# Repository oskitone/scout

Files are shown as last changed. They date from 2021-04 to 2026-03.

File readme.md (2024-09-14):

# Scout

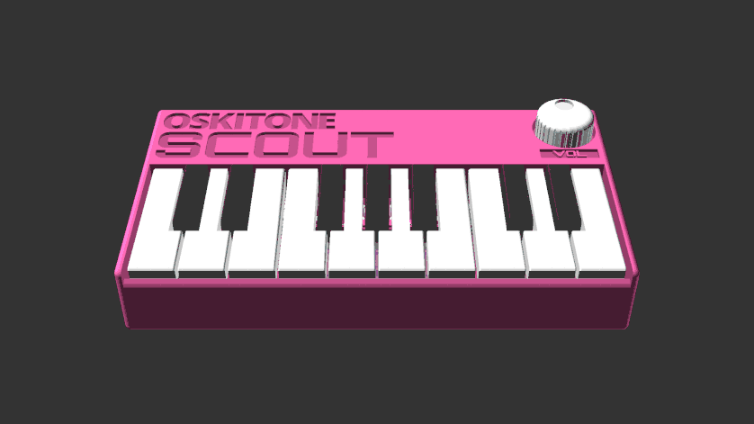
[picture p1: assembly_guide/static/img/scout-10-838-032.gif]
Scout


**scout** (_/skout/_):

1. _One sent to obtain information_
2. _Jean Louise “Scout” Finch, of Atticus Finch_
3. _The first synth from Oskitone to venture into the big ol' world of microcontrollers_

The Scout is:

- **Beginner-friendly:** All components are through-hole (instead of surface mount) for easier soldering, and full assembly takes about 45min. Standalone, battery-powered, doesn't need a computer or external speakers to work. Fun!
- **3D-Printable:** Besides the electronics and nuts and bolts, all parts are 3D-printed. And with a total width of ~160mm (about 6.3"), the Scout can fit on smaller, "Mini" (18x18x18cm) size print beds.
- **Hackable:** Arduino-compatible and fully open source! Hook up an [FTDI Serial TTL-232 cable](https://www.adafruit.com/product/70) (sold separately) to update its code using the Arduino IDE.
- **Minimally featured:** 1.5 octaves of keys, a volume knob, on/off switch, speaker, headphone jack. Monophonic square wave with fixed glide and octave.

In addition to it being the first microcontroller-controlled instrument from Oskitone, the Scout would also make a fine introductory DIY instrument for the budding electronics hobbyist. (Some experience soldering and a general familiarity with how electricity works are recommended though!)

As such, it is intentionally minimal, with the goal of the shortest possible time from starting the kit to making music with it. No MIDI/CV or other IO, as is. If you're looking for a full-featured studio instrument, this ain't it, bub! :)

**Demo:** [https://vimeo.com/587660426](https://vimeo.com/587660426)<br />
**Purchase a kit:** [https://www.oskitone.com/product/scout-synth-diy-electronics-kit](https://www.oskitone.com/product/scout-synth-diy-electronics-kit)<br />
**Assembly guide:** [https://oskitone.github.io/scout/](https://oskitone.github.io/scout/)<br />
**Blog post:** [https://blog.tommy.sh/posts/scout/](https://blog.tommy.sh/posts/scout/)

## 3D Models

The Scout's 3D-printed models are written in OpenSCAD.

### Dependencies

Assumes `poly555` and `apc` repos are in a sibling directory and are _both up to date_ on the `main` branch. Here's how I've got it:

    \ oskitone
        \ apc
        \ poly555
        \ scout

You'll also need to install the [Orbitron](https://fonts.google.com/specimen/Orbitron) font.

### Building

STLs are generated with `make_stls.sh`. Run `./make_stls.sh -h` for full flags list.

### Changelog

- **September 6, 2021:** Loosen knob fit on pot shaft (6cce7a7)
- **August 9, 2021:** Init (9b5ffe5)

## Documentation

To develop, `cd assembly_guide` then `npm run start`.

<!--
FOR TOMMY, to deploy:
GIT_USER=rocktronica USE_SSH=true npm run deploy
-->

## License

Designed by Oskitone. Please support future synth projects by purchasing from [Oskitone](https://www.oskitone.com/).

Creative Commons Attribution/Share-Alike, all text above must be included in any redistribution. See license.txt for additional details.

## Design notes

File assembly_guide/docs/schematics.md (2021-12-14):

---
id: schematics
title: "Schematics"
description: Scout circuit schematics
sidebar_label: Schematics
image: /img/schematics/scout.svg
hide_table_of_contents: true
---

Scout schematic

Scout keyboard_matrix schematic

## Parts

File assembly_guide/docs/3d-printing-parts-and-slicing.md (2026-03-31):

---
id: 3d-printing-parts-and-slicing
title: 3D-Printing Parts and Slicing
description: How to 3D-print your Scout's parts.
sidebar_label: Parts and Slicing
image: /img/scout_3d_printed_parts.png
slug: /3d-printing-parts-and-slicing
---

:::note
If you bought a kit with 3D-printed parts included, you can skip this section, but do [open up the enclosure](opening-the-enclosure.md) and confirm you have all the right pieces ready before continuing.
:::

## Download

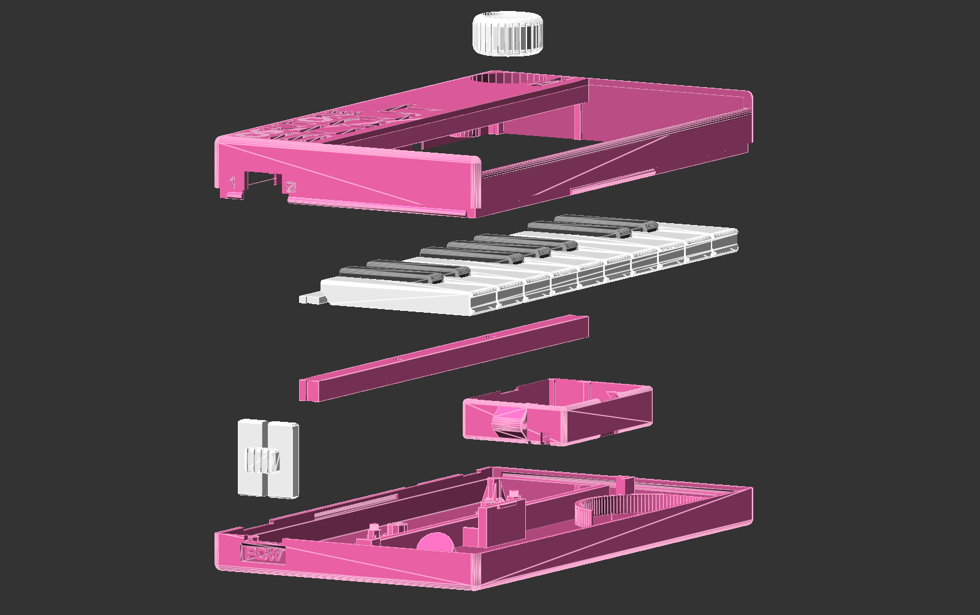
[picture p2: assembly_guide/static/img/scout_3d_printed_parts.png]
Scout 3D-printed parts


Download STLs of the models on [Thingiverse](https://www.thingiverse.com/thing:4933700) or [Printables](https://www.printables.com/model/76472-scout-synth).

## Slicing

There are seven files to print, taking about 11 hours total.

| Part | Layer Height | Supports? | Color change at height | Estimated Time |
| --- | --- | --- | --- | --- |
| battery_holder | .2mm | No | n/a | 40min |
| enclosure_bottom | .2mm | No | n/a | 3hr 10min |
| enclosure_top | .2mm | No | n/a | 3hr |
| keys_mount_rail  | .2mm | No | n/a | 30min |
| keys | .2mm | No | 7.2mm | 3hr |
| knob | .2mm | No | n/a | 20min |
| switch_clutch | .2mm | No | n/a | 20min |

**Notes:**

- Models assume Fused Deposition Modeling with a standard .4mm nozzle. Using a bigger nozzle will likely result in a loss of detail (like missing "VOL" label text on the enclosure_top) and possibly missing internal walls.
- You may find the bottoms of the keys stick together because the plastic has expanded too far into the gap between them. See if your slicer has a setting called something like ["Elephant foot compensation"](https://help.prusa3d.com/en/article/elephant-foot-compensation_114487). Otherwise you'll need to carefully cut off the excess plastic with a utility knife.
- The 3D-printed parts were designed using PLA. Other filament types like ABS are not recommended and will likely have fit or tolerance issues. (If you find that you need to drill or file your prints, that's a good sign there'll be other problems too.)
- 20% infill works well across all models. I wouldn't advise going lower than 15% on the keys.
- Some slicers have trouble with the "color change" GCODE. Try a smaller test print first if you're unfamiliar, and maybe try "pause at layer" instead of "color change".
- Any supports the models need they'll already have, they'll already be rotated to the correct orientation for printing, and they shouldn't need brims. Brims on the keys, in fact, could cause warping on removal. (If you're experimenting with not using FDM, try the `*-no_support` STLs that don't have supports.)
- Watch the first couple layers of the enclosure pieces while printing, especially around the text engravings -- if you see bad adhesion, stop the print to remedy the situation and start again.
- If the prints aren't fitting together well, check to see that the corners aren't bulging. See if your slicer has settings for "coasting" or "linear advance."
- The enclosure_top and switch_clutch both have narrow support walls that will break off when they're done printing.
- If your slicer has it, you can experiment with "variable layer height", but pay attention to the details on the enclosure's text engravings and the aforementioned supports.
- Similarly, you may also like to play around with "ironing" the tops of the keys to make them shiny and flat. _This will significantly increase print time!_

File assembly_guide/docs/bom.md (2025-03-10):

---
id: bom
title: Annotated BOM
description: Bill of Materials, annotated.
sidebar_label: Annotated BOM
image: /img/scout_assembly-16-420-8-128.gif
slug: /bom
hide_table_of_contents: true
---

| Designator | Designation | Quantity | Marking | Usage |
| --- | --- | --- | --- | --- |
| BT1 | 3.6v-4.5v | 1 | n/a | Power; wires to 3\*AAA battery pack |
| C1,C5 | 220uF | 2 | n/a | Big bypass cap, Amp output |
| C3 | 1uF | 1 | n/a | Amp gain |
| C2,C4,C6 | .1uF | 3 | 104 | Bypass caps, RESET pin cap (C4) |
| D1 | LED_CRGB | 1 | n/a | On/off+playing indicators |
| J1 | AudioJack2_SwitchT | 1 | n/a | Line out headphone jack |
| J2 | Conn_01x06_Male | 1 | n/a | Programming header |
| LS1 | Speaker, AZ40R 40mm x 5mm | 1 | n/a | Wires to output speaker |
| R1,R2 | 220 | 2 | Red Red Brown | LED current limiters |
| R3,R5 | 10k | 2 | Brown Black Orange | Brings volume closer to ear-safe level for line out, "pull up" resistor for RESET pin |
| R4 | 1m | 1 | Brown Black Green  | Drops volume even more before amp |
| RV1 | 10k Log, RV09AF-40-20K-A10K | 1 | n/a | Volume control |
| SW1 | SPDT, OS102011MA1QN1 | 1 | n/a | On/off power switch |
| SW2-SW18 | SPST, 6mm tall | 17 | n/a | Key buttons |
| U1 | ATmega328P-PU with bootloader | 1 | n/a | Microcontroller chip |
| U2 | LM386 | 1 | n/a | Amplifier chip |
| Y1 | 16.00MHz | 1 | n/a | Ceramic oscillator for microcontroller |

Also:

- 2 2-wire ribbon cables (or similar small gauge, stranded wire)
  - 1 7" for BT1
  - 1 3" for LS1
- 4 battery terminal contacts for BT1
  - 2 dual spring+button wire contacts (Keystone 181)
  - 1 tabbed spring contact (Keystone 5204)
  - 1 tabbed button contact (Keystone 5226)
- 2 DIP sockets
  - 1 28 pin for U1
  - 1 8 pin for U2
- 4 nuts and bolts
  - 2 4/40 square nuts
  - 2 4/40 3/4" machine screws

Alternate speakers for the AZ40R:

- PSR-40N08A05-JQ
- AS04008MR-21-R
- CMS-4051-058SP

Any circular 8ohm speaker that matches the dimensions will probably work, thought you may find you need a bit of hot glue to hold it in place.

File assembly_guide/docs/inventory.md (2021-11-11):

---
id: inventory
title: Inventory
description: What you'll need to gather before getting started.
sidebar_label: Inventory
image: /img/scout-10-838-032.gif
slug: /inventory
---

#### Required

- The [Oskitone Scout Synth DIY Electronics Kit](http://www.oskitone.com/product/scout-synth-diy-electronics-kit) and its 3D-printed parts
- Soldering iron and solder specifically for electronics
- Wire stripper or cutters
- 3 AAA batteries
- Headphones

#### Recommended

- Multimeter for debugging
- PCB vice or “helping hands” holder
- “Solder sucker” or desoldering braid
- Patience, patience, patience

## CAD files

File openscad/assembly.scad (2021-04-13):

/* TODO: extract into common parts repo */
use <../../poly555/openscad/lib/speaker.scad>;

include <enclosure_bottom.scad>;
include <keyboard_matrix_pcb.scad>;
include <keys.scad>;
include <mounting_rail.scad>;
include <utils.scad>;

peripheral_clearance = 5;

PCB_X = ENCLOSURE_WALL + offset / 2 + key_gutter;
PCB_Y = key_length - PCB_LENGTH + mount_length + ENCLOSURE_WALL + key_gutter;
PCB_Z = ENCLOSURE_FLOOR_CEILING + 2;

BREADBOARD_WIDTH = 35;
BREADBOARD_LENGTH = 50;

ARDUINO_WIDTH = 2.1 * 25.4;
ARDUINO_LENGTH = 2.7 * 25.4;

// https://www.taydaelectronics.com/loud-speaker-8-ohm-3w.html
SPEAKER_DIAMETER = 41.1;
SPEAKER_HEIGHT = 20;
SPEAKER_LENGTH = 71;

peripheral_length = max(BREADBOARD_LENGTH, ARDUINO_LENGTH, SPEAKER_LENGTH);

ENCLOSURE_WIDTH = PCB_X * 2 + PCB_WIDTH;
ENCLOSURE_LENGTH =
    ENCLOSURE_WALL + key_gutter + key_length + mount_length
    + peripheral_length + peripheral_clearance * 2;

DEFAULT_TOLERANCE = .1;

module assembly(
    show_keys = true,
    show_mounting_rail = true,
    show_pcb = true,
    show_peripherals = true,
    show_enclosure_bottom = true,

    tolerance = 0,
    quick_preview = true
) {
    if (show_keys) {
        keys_with_nut_locking_mount(
            tolerance = tolerance,
            quick_preview = quick_preview
        );
    }

    if (show_pcb) {
        e_translate([PCB_X, PCB_Y, PCB_Z]) {
            keyboard_matrix_pcb();
        }
    }

    if (show_enclosure_bottom) {
        enclosure_bottom();
    }

    if (show_mounting_rail) {
        mounting_rail_with_header_cavity();
    }

    if (show_peripherals) {
        y = PCB_Y + PCB_LENGTH - mount_length + mount_length
            + peripheral_clearance;
        z = ENCLOSURE_FLOOR_CEILING;

        height = 20;

        e_translate([peripheral_clearance, y, z]) {
            % cube([ARDUINO_WIDTH, ARDUINO_LENGTH, height]);
        }

        e_translate([peripheral_clearance * 2 + ARDUINO_WIDTH, y, z]) {
            % cube([BREADBOARD_WIDTH, BREADBOARD_LENGTH, height]);
        }

        translate([
            ENCLOSURE_WIDTH - SPEAKER_DIAMETER / 2 - ENCLOSURE_WALL,
            ENCLOSURE_LENGTH - peripheral_length / 2 - peripheral_clearance,
            z
        ]) {
            % speaker(SPEAKER_HEIGHT);
        }
    }
}

SHOW_KEYS = true;
SHOW_MOUNTING_RAIL = true;
SHOW_PCB = true;
SHOW_PERIPHERALS = true;
SHOW_ENCLOSURE_BOTTOM = true;

assembly(
    show_keys = SHOW_KEYS,
    show_mounting_rail = SHOW_MOUNTING_RAIL,
    show_pcb = SHOW_PCB,
    show_peripherals = SHOW_PERIPHERALS,
    show_enclosure_bottom = SHOW_ENCLOSURE_BOTTOM,

    tolerance = DEFAULT_TOLERANCE,
    quick_preview = $preview
);

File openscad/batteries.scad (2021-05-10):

AAA_BATTERY_DIAMETER = 10.5;
AAA_BATTERY_LENGTH = 44.5;

AAA_BATTERY_POSITIVE_CONTACT_MIN_LENGTH = .8;
AAA_BATTERY_POSITIVE_CONTACT_MAX_DIAMETER = 3.8;

AAA_BATTERY_TOTAL_LENGTH = AAA_BATTERY_LENGTH +
    AAA_BATTERY_POSITIVE_CONTACT_MIN_LENGTH;

module battery(
    reverse = false,
    $fn = 24
) {
    module _output() {
        translate([0, AAA_BATTERY_DIAMETER / 2, AAA_BATTERY_DIAMETER / 2]) {
            rotate([0, 90, 0]) {
                cylinder(
                    d = AAA_BATTERY_DIAMETER,
                    h = AAA_BATTERY_LENGTH
                );

                translate([0, 0, AAA_BATTERY_LENGTH]) {
                    cylinder(
                        d = AAA_BATTERY_POSITIVE_CONTACT_MAX_DIAMETER,
                        h = AAA_BATTERY_POSITIVE_CONTACT_MIN_LENGTH
                    );
                }
            }
        }
    }

    if (reverse) {
        translate([AAA_BATTERY_TOTAL_LENGTH, 0, 0]) {
            mirror([1, 0, 0]) {
                _output();
            }
        }
    } else {
        _output();
    }
}

module battery_array(
    count = 3,
    gutter = KEYSTONE_181_GUTTER,

    positive_x = KEYSTONE_181_BUTTON_LENGTH,
    negative_x = KEYSTONE_181_SPRING_COMPRESSED_LENGTH
) {
    plot = AAA_BATTERY_DIAMETER + gutter;

    for (i = [0 : count - 1]) {
        is_odd = i % 2 == 1;

        translate([is_odd ? positive_x : negative_x, i * plot, 0]) {
            battery(reverse = is_odd);
        }
    }
}

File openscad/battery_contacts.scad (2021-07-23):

KEYSTONE_181_HEIGHT = 7;
KEYSTONE_181_CONTACT_X = KEYSTONE_181_HEIGHT / 2;
KEYSTONE_181_CADENCE = 10.5;
KEYSTONE_181_WIDTH = KEYSTONE_181_CADENCE + KEYSTONE_181_CONTACT_X * 2;
KEYSTONE_181_DIAMETER = .5;

KEYSTONE_181_SPRING_LENGTH = 7.2;
KEYSTONE_181_SPRING_COMPRESSED_LENGTH = KEYSTONE_181_SPRING_LENGTH * .25;

KEYSTONE_181_BUTTON_LENGTH = 1.4;

KEYSTONE_181_GUTTER = 0;

KEYSTONE_180_CUT_LEAD_HEIGHT = 5;

// 5204: NEGATIVE SPRING WITH TAB
// 5226: POSITIVE BUTTON WITH TAB
KEYSTONE_5204_5226_WIDTH = 9.2;
KEYSTONE_5204_5226_LENGTH = .51;
KEYSTONE_5204_5226_FULL_LENGTH = 1; // includes lil tabs
KEYSTONE_5204_5226_HEIGHT = 10.4;
KEYSTONE_5204_5226_CONTACT_Z = 5.5;
KEYSTONE_5204_5226_TAB_WIDTH = 3;
KEYSTONE_5204_5226_TAB_HEIGHT = 17 - KEYSTONE_5204_5226_HEIGHT;
KEYSTONE_5204_5226_DIMPLE_LENGTH = 1;

DUAL = "dual";
BUTTON = "button";
SPRING = "spring";

module keystone_wire_contact(
    type = DUAL,
    flip = false,

    compressed = true,

    height = KEYSTONE_181_HEIGHT,
    contact_x = KEYSTONE_181_CONTACT_X,
    cadence = KEYSTONE_181_CADENCE,
    width = KEYSTONE_181_WIDTH,
    diameter = KEYSTONE_181_DIAMETER,

    spring_length = KEYSTONE_181_SPRING_LENGTH,
    spring_compressed_length = KEYSTONE_181_SPRING_COMPRESSED_LENGTH,

    button_length = KEYSTONE_181_BUTTON_LENGTH
) {
    e = .094;

    module _contact(
        contact_length,
        x = 0,
        $fn = 12
    ) {
        translate([x, 0, height / 2]) {
            rotate([270, 0, 0]) {
                cylinder(
                    d = height,
                    h = diameter + e
                );

                translate([0, 0, diameter]) {
                    cylinder(
                        d1 = height,
                        d2 = height * .67,
                        h = contact_length - diameter
                    );
                }
            }
        }
    }

    module _connector() {
        translate([contact_x, diameter / 2, height - diameter / 2]) {
            rotate([0, 90, 0]) {
                cylinder(
                    d = diameter,
                    h = cadence
                );
            }
        }
    }

    module arrange(z = 0) {
        y = flip ? KEYSTONE_181_HEIGHT / -2 : KEYSTONE_181_HEIGHT / 2;

        translate([0, z, y]) {
            rotate(flip ? [0, 0, 90] : [0, 180, -90]) {
                children();
            }
        }
    }

    module _spring() {
        _contact(
            compressed ? spring_compressed_length : spring_length, contact_x
        );
    }

    module _button(x = 0) {
        _contact(button_length, x);
    }

    module _dual_contacts() {
        arrange() {
            _spring();
            _button(width - contact_x);
            _connector();
        }
    }

    if (type == DUAL) {
        _dual_contacts();
    } else if (type == BUTTON) {
        arrange(AAA_BATTERY_DIAMETER / 2) {
            _button();

            translate([0, 0, height - e]) {
                cylinder(
                    d = diameter,
                    h = KEYSTONE_180_CUT_LEAD_HEIGHT + e
                );
            }
        }
    } else if (type == SPRING) {
        arrange() {
            _spring();

            translate([height / 2, 0, e - KEYSTONE_180_CUT_LEAD_HEIGHT]) {
                cylinder(
                    d = diameter,
                    h = KEYSTONE_180_CUT_LEAD_HEIGHT + e
                );
            }
        }
    }
}

module keystone_tabbed_contact(
    type = BUTTON,
    flip = false,
    show_tab = true,

    width = KEYSTONE_5204_5226_WIDTH,
    length = KEYSTONE_5204_5226_LENGTH,
    height = KEYSTONE_5204_5226_HEIGHT,

    contact_diameter = 6,
    contact_button_length = 1,
    contact_spring_length = KEYSTONE_181_SPRING_COMPRESSED_LENGTH,
    contact_z = KEYSTONE_5204_5226_CONTACT_Z,

    tab_width = KEYSTONE_5204_5226_TAB_WIDTH,
    tab_height = KEYSTONE_5204_5226_TAB_HEIGHT
) {
    e = .072;

    module _output() {
        cube([width, length, height]);

        if (show_tab) {
            translate([(width - tab_width) / 2, 0, -tab_height]) {
                cube([tab_width, length, tab_height + e]);
            }
        }

        translate([width / 2, length - e, contact_z]) {
            rotate([-90, 0, 0]) {
                cylinder(
                    d1 = contact_diameter,
                    d2 = contact_diameter * .67,
                    h = type == SPRING
                        ? contact_spring_length + e
                        : contact_button_length + e
                );
            }
        }
    }

    if (flip) {
        translate([0, 0, -contact_z]) {
            rotate([0, 0, 90]) {
                _output();
            }
        }
    } else {
        translate([0, width, -contact_z]) {
            rotate([0, 0, -90]) {
                _output();
            }
        }
    }
}

module battery_contacts(
    tolerance = 0,
    show_tabs = true,
    gutter = KEYSTONE_181_GUTTER,
    count = 3,
    end_terminal_bottom_right = true
) {
    e = .091;

    cavity_width = get_battery_holder_cavity_width(tolerance);
    start_on_right = end_terminal_bottom_right;

    function get_y(contact_width, i, is_dual = false) = (
        (AAA_BATTERY_DIAMETER + gutter) * i
        + (AAA_BATTERY_DIAMETER * (is_dual ? 2 : 1) - contact_width) / 2
    );

    if (floor(count) > 1) {
        for (i = [0 : floor(count)]) {
            is_even = i % 2 == 0;

            left_x = e;
            right_x = cavity_width - tolerance * 2 - e;

            z = AAA_BATTERY_DIAMETER / 2;

            if (i <= count - 2) {
                x = is_even
                    ? start_on_right ? right_x : left_x
                    : start_on_right ? left_x : right_x;

                translate([x, get_y(KEYSTONE_181_WIDTH, i, true), z]) {
                    keystone_wire_contact(
                        flip = start_on_right ? is_even : !is_even
                    );
                }
            }

            if (i == 0) {
                x = start_on_right ? left_x : right_x;

                translate([x, get_y(KEYSTONE_5204_5226_WIDTH, i), z]) {
                    keystone_tabbed_contact(
                        flip = !start_on_right,
                        type = BUTTON,
                        show_tab = show_tabs
                    );
                }
            } else if (i == count - 1) {
                x = start_on_right ? right_x : left_x;

                translate([x, get_y(KEYSTONE_5204_5226_WIDTH, i), z]) {
                    keystone_tabbed_contact(
                        flip = start_on_right,
                        type = SPRING,
                        show_tab = show_tabs
                    );
                }
            }
        }
    }
}

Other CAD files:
openscad/battery_holder.scad
openscad/enclosure.scad
openscad/enclosure_engraving.scad
openscad/enclosure_screw_cavities.scad
openscad/headphone_jack.scad
openscad/key_lip_endstop.scad
openscad/keys.scad
openscad/nuts_and_bolts.scad
openscad/pcb_fixtures.scad
openscad/pcb_mounting_columns.scad
openscad/pcb_stool.scad
openscad/scout.scad
openscad/scout_display.scad
openscad/scout_pcb.scad
openscad/speaker.scad
openscad/switch.scad
openscad/switch_clutch.scad
openscad/utils.scad

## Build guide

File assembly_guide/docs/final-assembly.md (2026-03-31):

---
id: final-assembly
title: Final assembly
description: How to assemble finish the Scout's assembly.
sidebar_label: Final assembly
image: /img/scout.jpg
slug: /final-assembly
---

:::note
You're almost done! Take your time to follow the directions in order.

And check out the [Assembly troubleshooting](assembly-troubleshooting.md) section if you run into any trouble.
:::

## Steps

### 1. Snap enclosure together

Align **enclosure top** onto **enclosure bottom** and snap the two halves together. Try to make sure the **keys mount rail** and **keys** stay aligned as you do this. It's an intentionally tight fit; be brave!

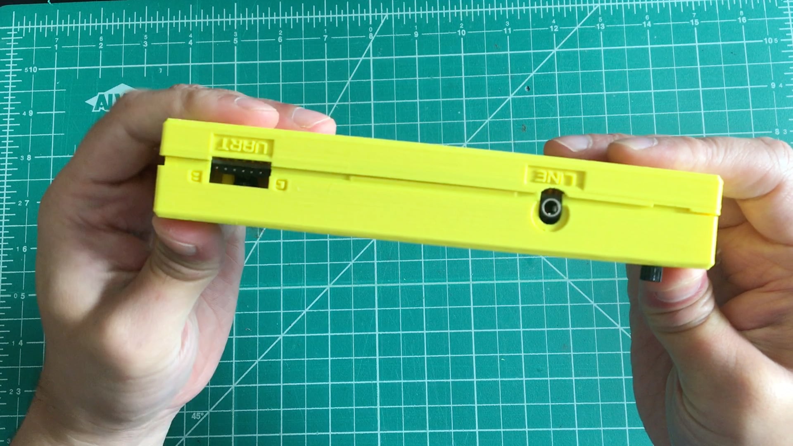
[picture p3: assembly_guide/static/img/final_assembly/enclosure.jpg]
enclosure


### 2. Quick test

With the **enclosure** together, try turning the Scout on and pressing each key.

You should find that:

1. No notes are playing unless you intentionally press them.
2. Some notes are kind of finicky and require more pressure. Don't worry, we'll fix those in a second!

If not, [pop the enclosure open](opening-the-enclosure.md) and revisit adding the keys in the [Assemble Top](assemble-top.md) step.

### 3. Add knob

Fix **knob** onto the volume pot shaft, aligning its dimple to to the little marker on the top of the pot shaft.

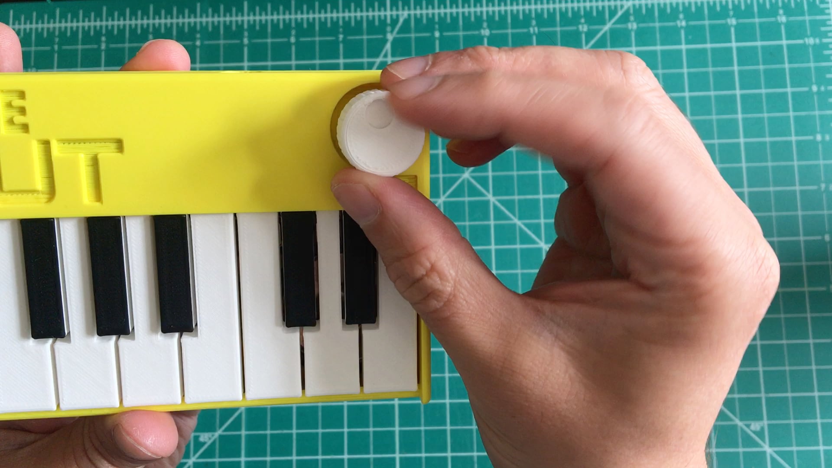
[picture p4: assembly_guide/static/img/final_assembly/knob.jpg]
knob


### 4. Add machine screws

Slide two **machine screws** up through the bottom of the **enclosure bottom**.

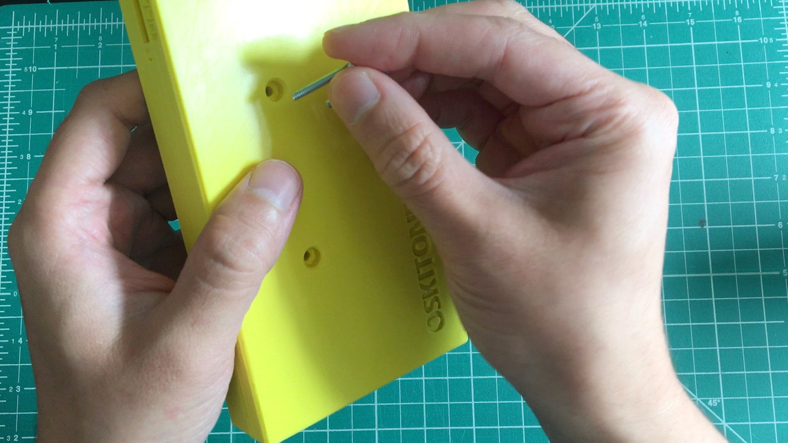
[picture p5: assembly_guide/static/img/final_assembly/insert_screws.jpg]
insert screws


If they don't insert easily, you may have something misaligned inside. [pop the enclosure open](opening-the-enclosure.md) and make sure the **PCB**, **keys mount rail**, and **keys** are all lined up correctly.

### 5. Tighten screws

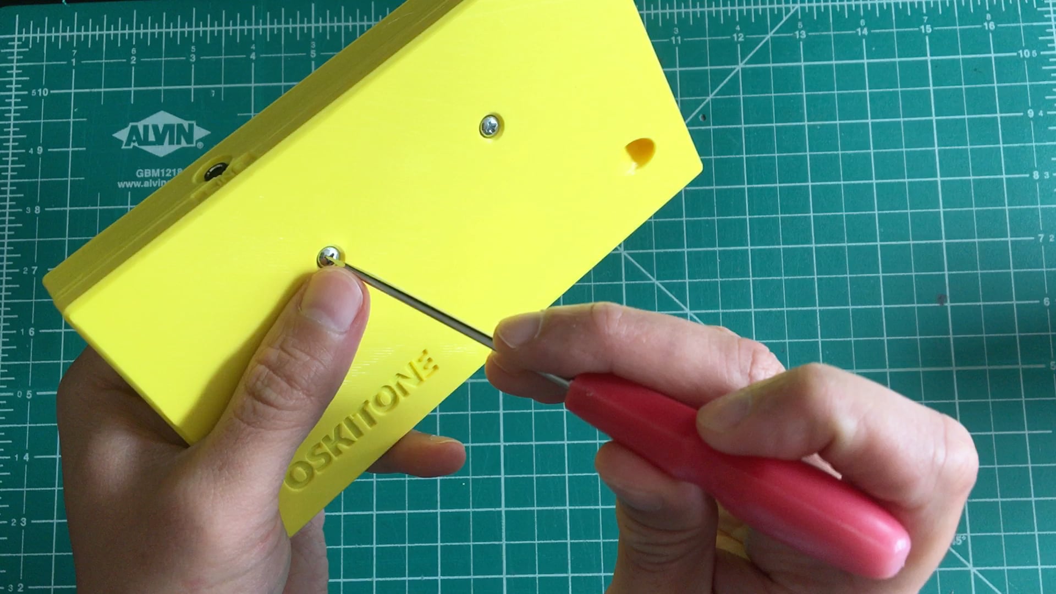
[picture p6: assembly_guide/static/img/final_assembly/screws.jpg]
screws


1. With the Scout on (and no notes playing, see above in "Quick test"), cautiosly tighten the **screws**.
2. If/when a note starts playing, that indicates the screw is too tight. Loosen it until the note subsides.

As you may have figured out, the screws hold the Scout together _but also control the keys' "action"_ (how much effort is required to trigger each note). Without them, keys towards the middle are more difficult to play.

You basically want the screws tight enough that all keys require the same amount of effort, so adjust them until everything feels good.

## All done!

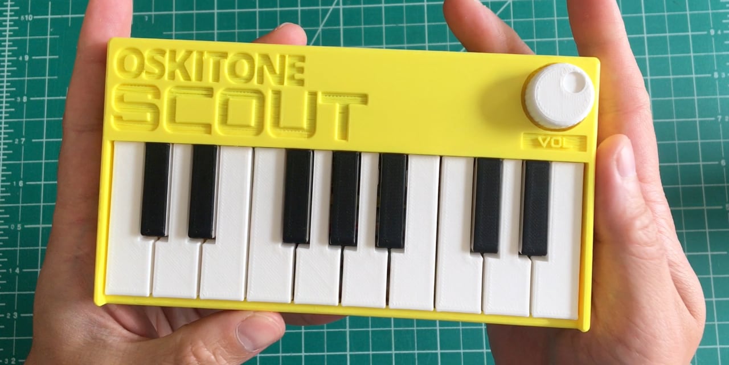
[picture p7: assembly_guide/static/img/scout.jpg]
All done!


## What's next

### Feedback

When you can, please [let me know](https://www.oskitone.com/contact) how it went for you:

- **What did you like?** Did you have fun?!
- Not including printing time, about **how long did it take?**
- **How'd the kit show up?** Were there any parts missing or damaged? Or any **problems with the instructions**?
- The Scout is intentionally simple, but that doesn't mean future kits will be too. Any **feature requests** for the next Oskitone instrument?

I act and rely on customers' feedback to make the next products even better. Even just knowing that you got it done successfully is valuable feedback, so I do want to hear from you. Thank you so much!

### Share your make

Like your Scout? I'd love to have you share that!

- If you 3D-printed it at home, share your make on the [Thingiverse](https://www.thingiverse.com/thing:4933700) or [Printables](https://www.printables.com/model/76472-scout-synth) page where you downloaded the models. It's a good signal to other potential makers to see successful makes.
- Tell your friends, post on social, etc. You know the deal!

### Follow along

I run an informal [email list](https://www.oskitone.com/mailing-list) to update folks on projects, notify when new products hit the store, and get early feedback and share ideas. If you're interested in what's next with Oskitone, it's the best way to stay updated.

<iframe
  scrolling="no"
  style={{width: "100%", height: "135px", border: "none"}}
  src="https://buttondown.com/oskitone?as_embed=true"
></iframe>

Powered by [Buttondown](https://buttondown.com/refer/oskitone). Read previous emails in the archive [here](https://buttondown.com/oskitone/archive/).

And, of course, follow [@oskitone on Instagram](https://www.instagram.com/oskitone).

### Further reading

For the curious, I've written [a blog post where you can read more about the Scout's development and history](https://blog.tommy.sh/posts/scout/).

Each Oskitone product gets it's own blog post, so dig around in there and see if there's anything else you find interesting.

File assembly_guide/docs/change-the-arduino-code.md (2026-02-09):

---
id: change-the-arduino-code
title: Change the Arduino code
description: Hack, hack, hack, hack, hack, hack.
sidebar_label: Change the Arduino code
image: /img/hack/serial-plotter.png
slug: /change-the-arduino-code
---

:::info
This section is optional!
:::

:::tip
If you're building your [Scout from scratch](bom.md) and sourced your own ATmega328, it _must_ have a bootloader programmed onto it for these instructions to work.
:::

## Required equipment

To keep the Scout's price more accessible, it doesn't come with a built-in USB controller chip, so, out of the box, you can't easily hook it up to your computer as-is.

Thankfully, that USB chip is readily available as a cable, which you can connect between your Scout and your computer.

These cables have been tested and confirmed to work with the Scout:

- [FTDI Serial TTL-232 USB Cable](https://www.adafruit.com/product/70) from Adafruit
- [USB Serial Cable](https://cornfieldelectronics.com/cfe/products/buy.php?productId=usbcable&PHPSESSID=oos5v81hlitjvb0grhgolsrq96) from Cornfield Electronics
- [FT232RL FTDI USB to TTL Serial Adapter](http://www.hiletgo.com/ProductDetail/2152064.html) from HiLetgo

:::note
Successfully use a different brand of cable? [Contact me](https://www.oskitone.com/contact) and I can add it to the list.
:::

## Steps

Ready to experiment and get your hands dirty with some code?

1. Install the [Arduino IDE](https://www.arduino.cc/en/software) and follow their instructions to install whatever drivers you'd need for an Arduino Uno.
2. With the Scout's power off, connect the Scout's UART header to your computer using one of the cables listed above.
   1. The Scout's UART header has "B" and "G" labels on its sides to match the cables Black and Green wires.
   2. The cable provides power to the Scout, so it should now be on and working normally
   3. **Double check that the power switch is OFF!** Leaving it on can permanently damage the microcontroller or batteries!
3. In the IDE, under "Tools->Board", select "Arduino Uno". Under "Tools->Port" select your new cable; its exact name will depend on the brand. If you're not sure which it is, try unplugging and restarting the IDE -- whichever it was will no longer be listed, so you'll know which it is when reconnecting and restarting.
4. Download the code from this repo and load `arduino/scout.ino` in the Arduino IDE. You'll also need the [`CircularBuffer`](https://docs.arduino.cc/libraries/circularbuffer/) and [`Keypad`](https://docs.arduino.cc/libraries/keypad/) libraries, so open up "Tools->Manage libraries" and search for those to install them.
   1. Try uploading this to the Scout by going to "Sketch->Upload". If it works, after 10 seconds or so, it will blink just like it does when you switch its power on. If it doesn't work, the IDE will print out an error that you can google to find out how to fix.
   2. Experiment with the `octave` and `glide` values at the top of `scout.ino` and observe how your Scout has changed its sound.
5. "Blink"
   1. The Arduino IDE has a default program called "Blink" (available in "File->Examples->Basics->Blink").
   2. After uploading, the Scout won't be playable anymore but one of the colors on the RGB LED should blink off and on.
   3. Try changing the delay values in the example to make it blink faster or slower.
   4. Follow the steps above to bring the original Scout code back.

## Serial debugging

Check out the `printToSerial` variable at the top of `scout.ino`. Setting it to `true` and opening up the Arduino's Serial Plotter while playing notes will visualize the notes being held and how the playing frequency glides between its targets.

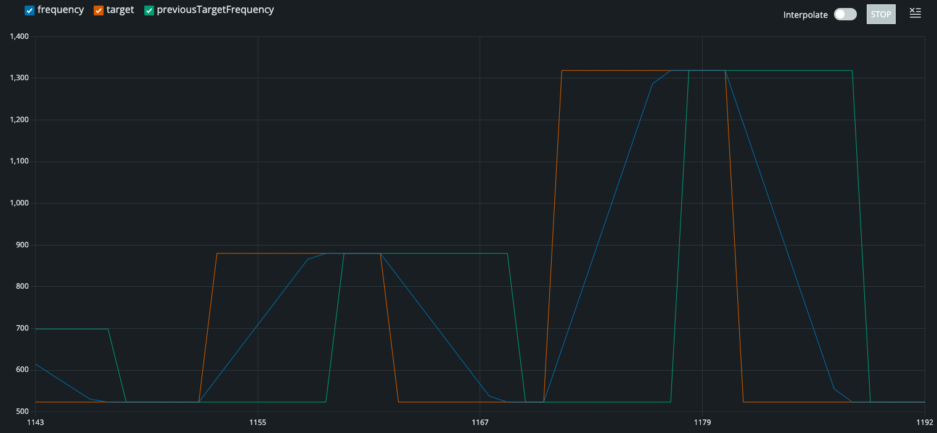
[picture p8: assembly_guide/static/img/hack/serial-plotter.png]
Screengrab of the Arduino serial plotter visualizing the Scout's frequency math


Now swap `frequency.print();` in the `loop()` for `buffer.print();` and switch to the Serial Monitor, and you'll get a running list of the indexes of the key(s) the Scout sees being played.

:::note
All this observation slows down the Scout's performance/glide. Remember to put `printToSerial` back to `false` before disconnecting from your computer!
:::

## Pins

Once you're comfortable with the Arduino code and really want to expand on what the Scout can do, take a look at the unpopulated HACK header on the PCB. It exposes all the unused pins on the ATmega328 that are safe to use for whatever you'd like:

| HACK | ATmega pins | Description |
| --- | --- | --- |
| VCC | n/a | Voltage from batteries or USB |
| A0-A5 | 23-28 | Analog pins |
| D12 | 18 | There's only one unused digital pin, and this is it |
| SWC, SW1-SW3 | 16; 6,11,12 | Unused spots in the key matrix |
| GND | n/a | Ground |

## Troubleshooting

* Does the ATmega328 have a [bootloader](https://docs.arduino.cc/retired/hacking/software/Bootloader/) on it?
* Is the chip all the way in its socket at the correct orientation?
* Do you have the right Arduino libraries installed?
* Confirm the Scout powers up and operates with just the cable (and Scout's power switch off!).
* Are you using one of the [known good](#required-equipment) FTDI cables? Confirm it's plugged in with green/black sides correctly.
* In the Arduino IDE, confirm you've got the right board selected, and try different ports.
* Take a closer look at the at the [UART header and its cap's soldering](prep-for-hacking) if you haven't already. Refer to the [schematics](schematics) and confirm its contact to the appropriate chip pins with a multimeter's continuity tester.
* As a last resort, try swapping to a new chip. Make sure it has a bootloader.

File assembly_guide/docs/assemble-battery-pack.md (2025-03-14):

---
id: assemble-battery-pack
title: Assemble battery pack
description: How to assemble the Scout's battery pack.
sidebar_label: Assemble battery pack
image: /img/pcb_assembly/010308@0.5x.jpg
slug: /assemble-battery-pack
---

## Steps

1. Insert tabbed battery contact terminals
   1. The springed contact goes to the spot with a "-".
   2. The flat, button contact goes near "+". Its button should face inward towards where the battery will be.
   3. These tabbed contacts will have a tight fit! You can use pliers to push/pull them in, then fold their tabs over to hold them in place.
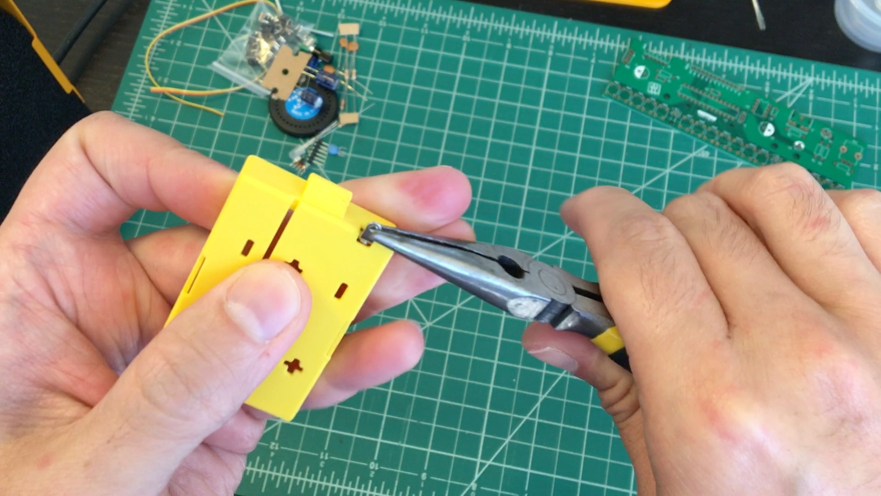
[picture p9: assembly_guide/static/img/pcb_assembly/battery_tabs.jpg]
battery_tabs
     
2. Insert wire dual contacts
   1. Again, springs go to "-" and buttons to "+".
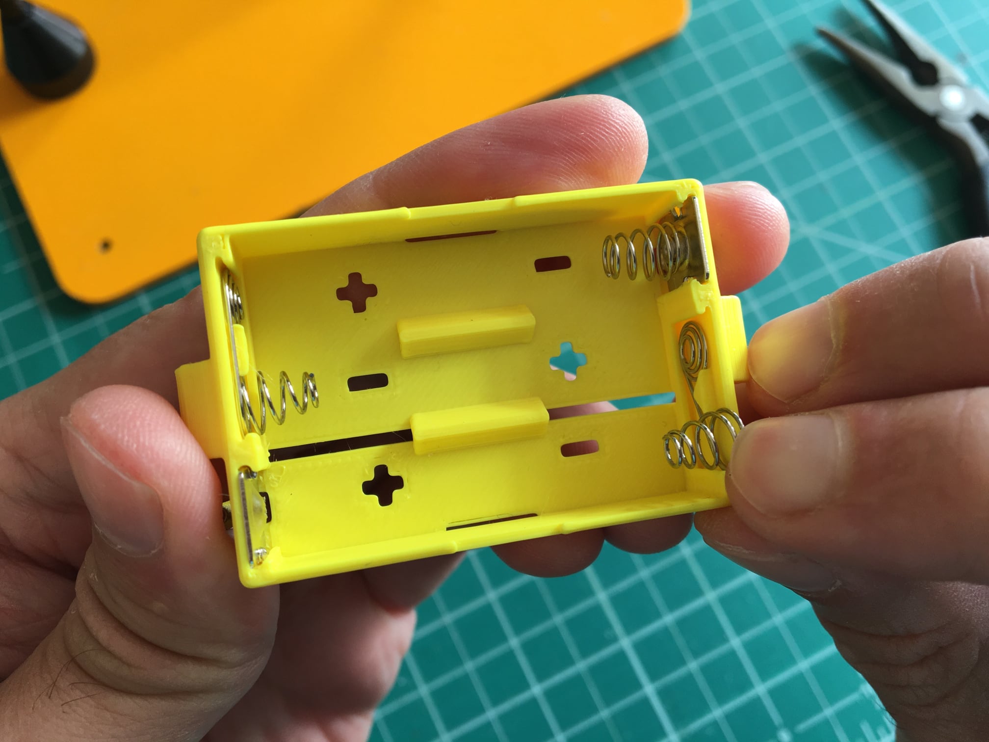
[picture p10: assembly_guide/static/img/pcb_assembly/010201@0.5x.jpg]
      
3. Add wire
   1. Cut your ribbon cable into two pieces of about 7" and 3".
   2. With the battery holder oriented so its "+" contact tab is on the left and "-" on the right, thread the 7" ribbon cable through the hitch on the left, about halfway though, and then split the bottom pair of wires.
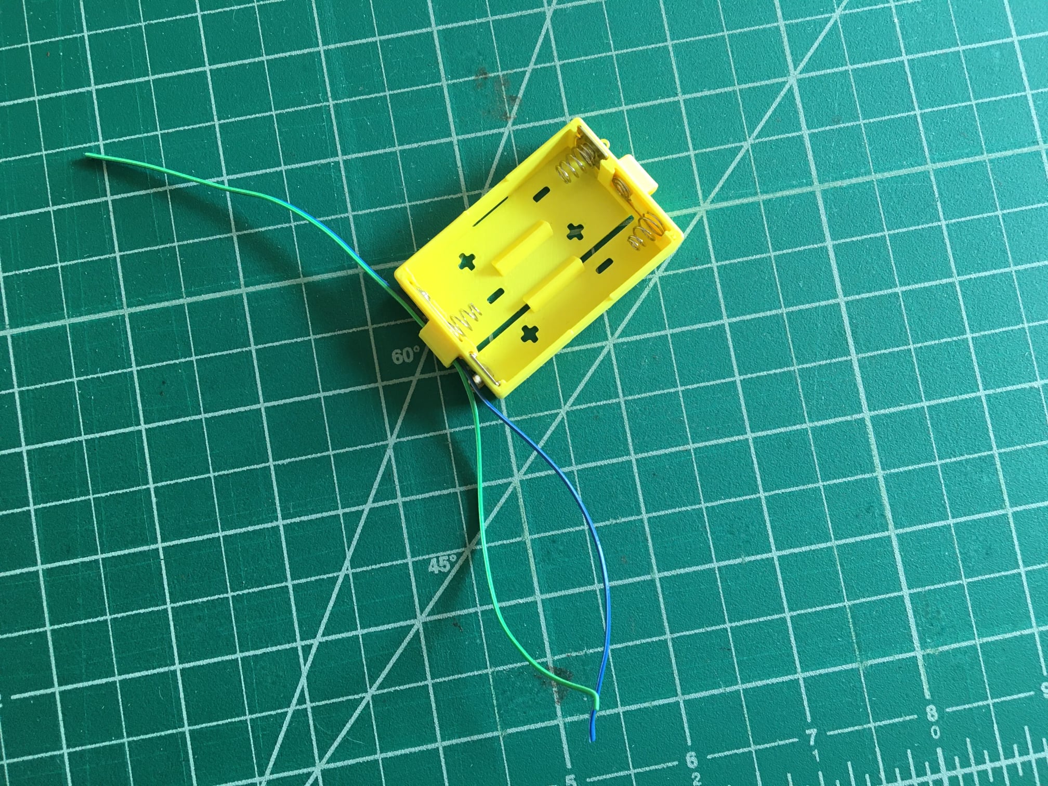
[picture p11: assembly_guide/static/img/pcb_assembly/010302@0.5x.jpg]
      
   3. Thread the darker wire of the now separated pair through the channel on the bottom of the battery holder and up through the right hitch. (Your ribbon cable will probably have different colors, and that's okay! A common convention is to use the darker color for "-" and the lighter one for "+".)
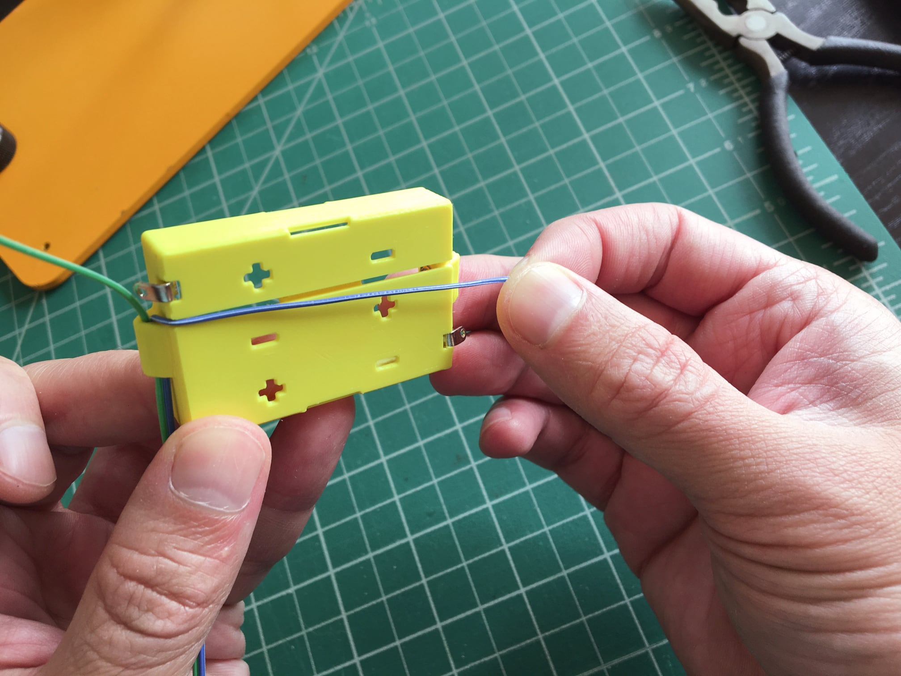
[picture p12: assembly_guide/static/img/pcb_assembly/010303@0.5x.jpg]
      
   4. Strip 1/4" of insulation off that right wire and solder to its contact tab. Try not to melt the plastic around it!
   5. Cut the wire on the left to meet its tab, then strip and solder it.
   6. Separate and strip the other side of wires. Make sure they don't touch!
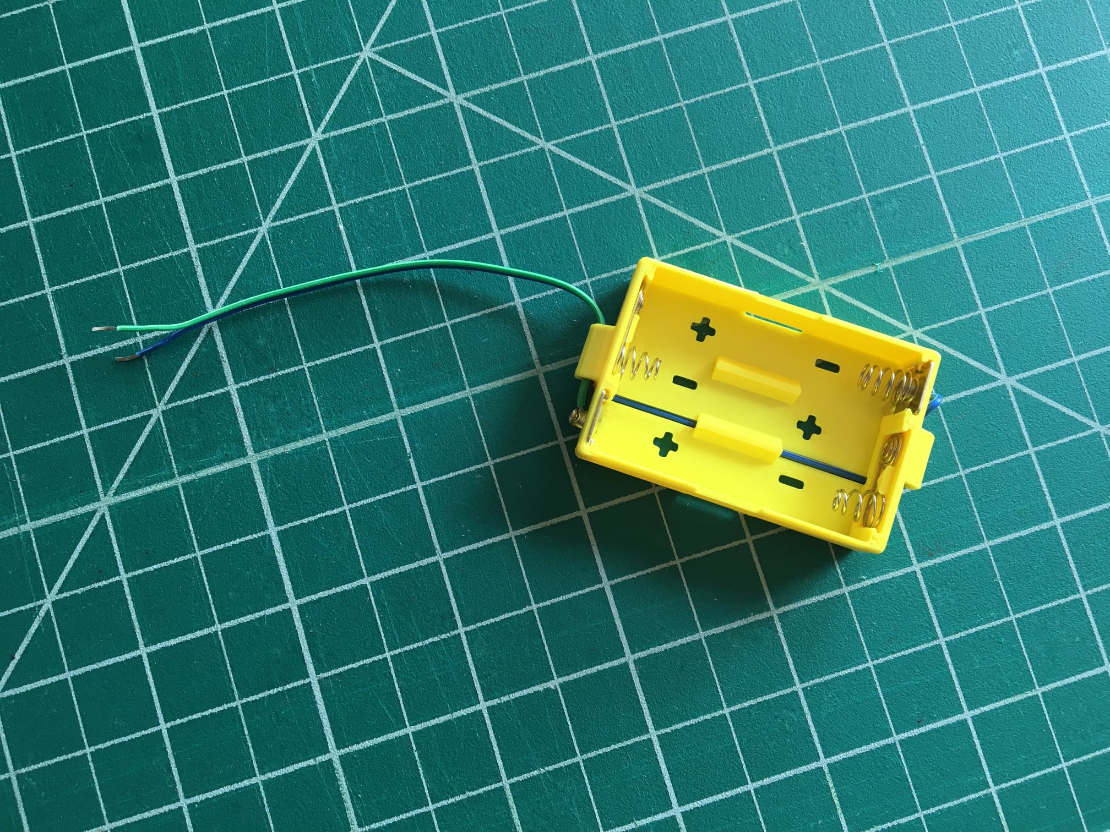
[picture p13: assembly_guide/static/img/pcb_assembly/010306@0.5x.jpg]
      
   7. Insert three AAA batteries, matching their "+" and "-" sides to the battery holder's labels.

## Test

Using a multimeter, measure the total voltage on those two wires. It should measure the sum of the three individual batteries' voltages -- ideally 3.6 to 4.5, depending on what kind of batteries they are. When done, remove the batteries to prevent accidentally draining them if the exposed wires touch.

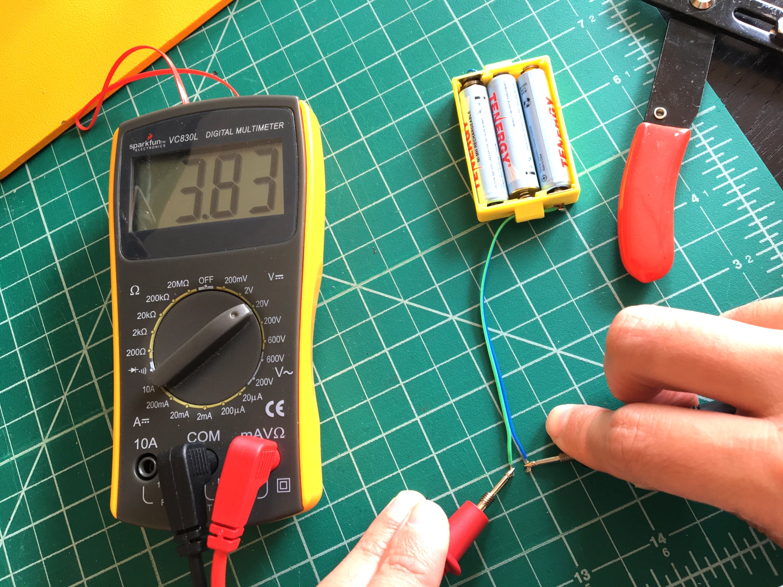
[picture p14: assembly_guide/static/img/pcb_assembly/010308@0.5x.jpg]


If you're having trouble with your multimeter, try measuring each battery individually and see if they read as you expect. Then install them into the battery pack and check their combined voltage.

Not working as expected? Check the [PCB troubleshooting](pcb-troubleshooting.md) section. Otherwise, continue to the next step.

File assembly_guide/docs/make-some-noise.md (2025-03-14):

---
id: make-some-noise
title: Make some noise
description: How to start getting noises out of the Scout.
sidebar_label: Make some noise
image: /img/pcb_assembly/050300@0.5x.jpg
slug: /make-some-noise
---

## Steps

1. Solder volume potentiometer (aka "pot") **RV1**, resistor **R3** (10k), and headphone jack **J1**.
   - A trick to get the pot to snap in better is to _gently_ push its tabs inward before popping it onto the PCB.
   - Make sure **RV1** and **J1** are pushed all the way into PCB before soldering all the way.
   - You can use a bit of tape or "Blu-Tack" adhesive to hold **J1** in place as you solder.
2. Connect your headphones into the headphone jack. _Push firmly until it clicks in all the way._

## Test

With power on, turn up the volume with the potentiometer and press **SW2**. You should hear a tone from the headphones in both the left and right channels. Power off.

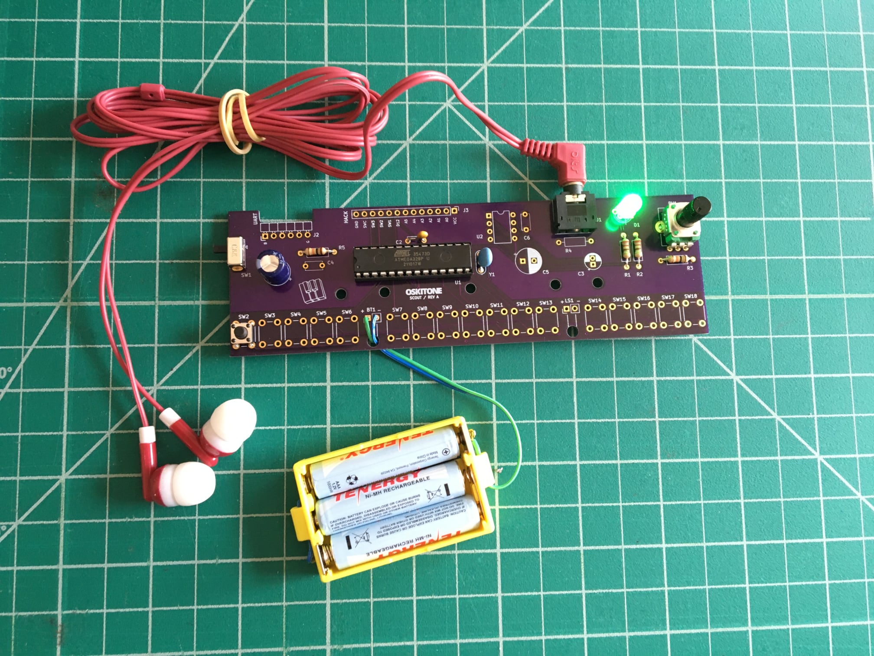
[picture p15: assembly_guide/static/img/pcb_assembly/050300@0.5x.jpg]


If only one side of the headphones is making noise, check to see that the headphone jack is pushed all the way in.

Not working as expected? Check the [PCB troubleshooting](pcb-troubleshooting.md) section. Otherwise, continue to the next step.

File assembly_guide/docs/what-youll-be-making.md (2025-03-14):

---
id: what-youll-be-making
title: Oskitone Scout Assembly Guide
sidebar_label: What You'll Be Making
description: How to solder and assemble the Oskitone Scout Electronics Kit
image: /img/scout-10-838-032.gif
slug: /
---

Scout

**Purchase:**

- [Scout Synth (fully assembled)](https://www.oskitone.com/product/scout-synth)
- [Scout Synth DIY Electronics Kit](https://www.oskitone.com/product/scout-synth-diy-electronics-kit)

## What You'll Be Making

**scout** (_/skout/_):

1. _One sent to obtain information_
2. _Jean Louise “Scout” Finch, of Atticus Finch_
3. _The first synth from Oskitone to venture into the big ol' world of microcontrollers_

A finished Scout

The Scout is:

- **Beginner-friendly:** All components are through-hole (instead of surface mount) for easier soldering, and full assembly takes about 45min. Standalone, battery-powered, doesn't need a computer or external speakers to work. Fun!
- **3D-Printable:** Besides the electronics and nuts and bolts, all parts are 3D-printed. And with a total width of ~160mm (about 6.3"), the Scout can fit on smaller, "Mini" (18x18x18cm) size print beds.
- **Hackable:** Arduino-compatible and fully open source! Hook up an [FTDI Serial TTL-232 cable](https://www.adafruit.com/product/70) (sold separately) to update its code using the Arduino IDE.
- **Minimally featured:** 1.5 octaves of keys, a volume knob, on/off switch, speaker, headphone jack. Monophonic square wave with fixed glide and octave.

In addition to it being the first microcontroller-controlled instrument from Oskitone, the Scout would also make a fine introductory DIY instrument for the budding electronics hobbyist. (Some experience soldering and a general familiarity with how electricity works are recommended though!)

As such, it is intentionally minimal, with the goal of the shortest possible time from starting the kit to making music with it. No MIDI/CV or other IO, as is. If you're looking for a full-featured studio instrument, this ain't it, bub! :)

<p><iframe src="https://player.vimeo.com/video/641270244" width="640" height="360" frameborder="0" allow="autoplay; fullscreen" allowfullscreen></iframe></p>

More information about the Scout, its development, and history: [https://blog.tommy.sh/posts/scout/](https://blog.tommy.sh/posts/scout/)

### Disclaimers

You've been warned!

:::warning
Not a toy. Choking hazard. Small parts. Not for children under 3 years.
:::

## About this guide

To save cost, trees, and frustration from outdated information, printed instructions are not included by default with Scout kits. This online guide will always be up to date and the best source of information for how to assemble your new Scout.

Thank you for understanding!

:::note
If you run into any problems with your build or something in the guide seems incorrect, please [please _email_ me to let me know](https://www.oskitone.com/contact)! I'll do my best to help you, and your feedback will help improve the guide and other future Oskitone designs.
:::

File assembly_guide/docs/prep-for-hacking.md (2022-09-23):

---
id: prep-for-hacking
title: Prep for hacking
description: Optionally solder the parts required to change the Scout's code.
sidebar_label: Prep for hacking
image: /img/pcb_assembly/090200@0.5x.jpg
slug: /prep-for-hacking
---

:::note
If you have no intention of ever changing the Scout's code, you can skip this part and it will work perfectly fine. But, you know, you're here, so you might as well!
:::

## Steps

1. Solder **J2** header and **C4** (.1uF, marked 104) cap.
   - Try to get **J2**'s pins parallel to the PCB and sticking straight out.

## Test

See ["Change the Arduino code" section](change-the-arduino-code) on how to use this!

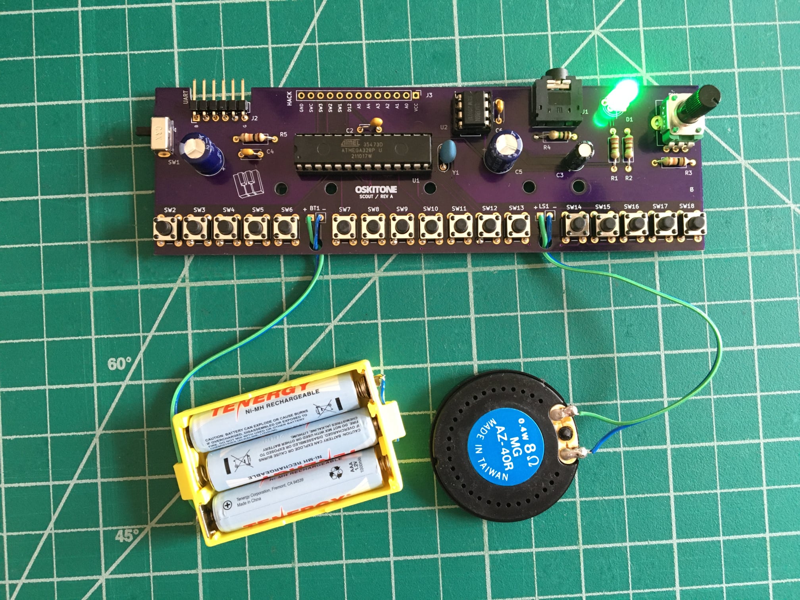
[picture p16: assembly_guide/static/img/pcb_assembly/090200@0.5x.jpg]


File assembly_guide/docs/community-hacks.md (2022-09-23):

---
id: community-hacks
title: Community hacks
description: Hack, hack, hack, hack, hack, hack.
sidebar_label: Community hacks
image: /img/scout-10-838-032.gif
slug: /community-hacks
---

:::info
This section is optional!
:::

:::note
Got a hack you want to share? [Contact me](https://www.oskitone.com/contact) and I can add it to the list.
:::

## Community hacks

- **[arpeggio_hack](https://github.com/shamlian/scout/tree/arpeggio_hack) from [Steven Shamlian](https://github.com/shamlian):** Adds polyphony by arpeggiating through the held notes. The full hack requires diodes on the switches to prevent key ghosting, but otherwise the Arduino code can work w/o any hardware changes... provided you only play certain chords or don't mind the occasional wrong note. Pretty interesting!
- **[MozziScout](https://github.com/todbot/MozziScout) from [todbot](https://todbot.com/):** With some careful pin swapping on the ATmega328, the Scout can use [Mozzi](https://sensorium.github.io/Mozzi/), the popular sound synthesis library for Arduino. For this hack, it's a good idea to plug into an amplifier &mdash; the new sounds your Scout will make are much richer than what its built-in speaker is capable!
- **[2-piece Keyboard Mod](https://cults3d.com/en/3d-model/game/oskitone-scout-2-piece-keyboard-mod) from [Cyb3rn0id](https://cults3d.com/en/users/Cyb3rn0id/creations):** If your 3D printer can't easily do the color channge GCODE for the keyboard color swap, this mod splits the keys' colors into two parts that snap and glue together.
- **[Arduino Soundlab](https://www.hackster.io/john-bradnam/arduino-soundlab-bf8593) from John Bradnam:** Scout keys on a non-Scout synth? Sure! This hack swaps out the ATmega328 for an Arduino Nano and custom PCB to add FM synthesis.

## Other ideas

- For extra stability, add ruber feet to the bottom of your Scout.

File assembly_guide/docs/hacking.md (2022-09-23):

---
id: hacking
title: Hacking
description: Hack, hack, hack, hack, hack, hack.
sidebar_label: Hacking
image: /img/scout-10-838-032.gif
slug: /hacking
---

:::info
This section is optional!
:::

## Required equipment

To keep the Scout's price more accessible, it doesn't come with a built-in USB controller chip, so, out of the box, you can't easily hook it up to your computer as-is.

Thankfully, that USB chip is readily available as a cable, which you can connect between your Scout and your computer.

These cables have been tested and confirmed to work with the Scout:

- [FTDI Serial TTL-232 USB Cable](https://www.adafruit.com/product/70) from Adafruit
- [USB Serial Cable](https://cornfieldelectronics.com/cfe/products/buy.php?productId=usbcable&PHPSESSID=oos5v81hlitjvb0grhgolsrq96) from Cornfield Electronics
- [FT232RL FTDI USB to TTL Serial Adapter](http://www.hiletgo.com/ProductDetail/2152064.html) from HiLetgo

:::note
Successfully use a different brand of cable? [Contact me](https://www.oskitone.com/contact) and I can add it to the list.
:::

## Change the Arduino code

Ready to experiment and get your hands dirty with some code?

1. Install the [Arduino IDE](https://www.arduino.cc/en/software) and follow their instructions to install whatever drivers you'd need for an Arduino Uno.
2. With the Scout's power off, use an [FTDI Serial TTL-232 cable](https://www.adafruit.com/product/70) to connect the Scout's UART header to your computer.
   1. The Scout's UART header has "B" and "G" labels on its sides to match the cables Black and Green wires.
   2. The cable provides power to the Scout, so it should now be on and working normally
   3. **Double check that the power switch is OFF!** Leaving it on can permanently damage the microcontroller or batteries!
3. In the IDE, under "Tools->Board", select "Arduino Uno". Under "Tools->Port" select your new cable; its exact name will depend on the brand. If you're not sure which it is, try unplugging and restarting the IDE -- whichever it was will no longer be listed, so you'll know which it is when reconnecting and restarting.
4. Download the code from this repo and load `arduino/scout.ino` in the Arduino IDE. You'll also need the `CircularBuffer` and `Keypad` libraries, so open up "Tools->Manage libraries" and search for those to install them.
   1. Try uploading this to the Scout by going to "Sketch->Upload". If it works, after 10 seconds or so, it will blink just like it does when you switch its power on. If it doesn't work, the IDE will print out an error that you can google to find out how to fix.
   2. Experiment with the `octave` and `glide` values at the top of `scout.ino` and observe how your Scout has changed its sound.
5. "Blink"
   1. The Arduino IDE has a default program called "Blink" (available in "File->Examples->Basics->Blink").
   2. After uploading, the Scout won't be playable anymore but one of the colors on the RGB LED should blink off and on.
   3. Try changing the delay values in the example to make it blink faster or slower.
   4. Follow the steps above to bring the original Scout code back.

Once you're comfortable with the Arduino code and really want to expand on what the Scout can do, take a look at the unpopulated HACK header on the PCB. It exposes all the unused pins on the ATmega328 that are safe to use for whatever you'd like:

| HACK | ATmega pins | Description |
| --- | --- | --- |
| VCC | n/a | Voltage from batteries or USB |
| A0-A5 | 23-28 | Analog pins |
| D12 | 18 | There's only one unused digital pin, and this is it |
| SWC, SW1-SW3 | 16; 6,11,12 | Unused spots in the key matrix |
| GND | n/a | Ground |

## Community hacks

- **[arpeggio_hack](https://github.com/shamlian/scout/tree/arpeggio_hack) from [Steven Shamlian](https://github.com/shamlian):** Adds polyphony by arpeggiating through the held notes. The full hack requires diodes on the switches to prevent key ghosting, but otherwise the Arduino code can work w/o any hardware changes... provided you only play certain chords or don't mind the occasional wrong note. Pretty interesting!
- **[MozziScout](https://github.com/todbot/MozziScout) from [todbot](https://todbot.com/):** With some careful pin swapping on the ATmega328, the Scout can use [Mozzi](https://sensorium.github.io/Mozzi/), the popular sound synthesis library for Arduino. For this hack, it's a good idea to plug into an amplifier &mdash; the new sounds your Scout will make are much richer than what its built-in speaker is capable!
- **[2-piece Keyboard Mod](https://cults3d.com/en/3d-model/game/oskitone-scout-2-piece-keyboard-mod) from [Cyb3rn0id](https://cults3d.com/en/users/Cyb3rn0id/creations):** If your 3D printer can't easily do the color channge GCODE for the keyboard color swap, this mod splits the keys' colors into two parts that snap and glue together.

:::note
Got a hack you want to share? [Contact me](https://www.oskitone.com/contact) and I can add it to the list.
:::

## Other ideas

- For extra stability, add ruber feet to the bottom of your Scout.

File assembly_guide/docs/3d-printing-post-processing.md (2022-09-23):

---
id: 3d-printing-post-processing
title: 3D-Printing Post-Processing
description: Getting your new 3D prints ready.
sidebar_label: Post-Processing
image: /img/scout_3d_printed_parts.png
slug: /3d-printing-post-processing
---

:::note
If you bought a kit with 3D-printed parts included, you can skip this section, but do [open up the enclosure](opening-the-enclosure.md) and confirm you have all the right pieces ready before continuing.
:::

Scout 3D-printed parts

As a reminder, you should have seven new prints. From top to bottom:

* knob
* enclosure top
* keys
* keys mount rail
* battery holder
* switch clutch
* enclosure bottom

## Post-processing

The **enclosure top** and **switch clutch** pieces both have print supports, highlighted here:

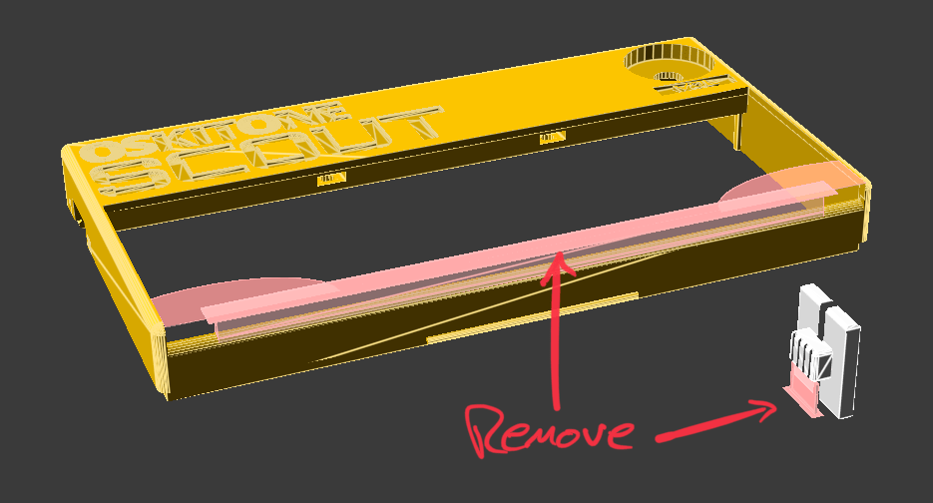
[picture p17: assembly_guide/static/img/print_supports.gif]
Built-in print supports on the Scout's enclosure top and switch clutch pieces


1. Snap off supports
2. Use a utility knife to trim off any excess plastic on the **enclosure top**

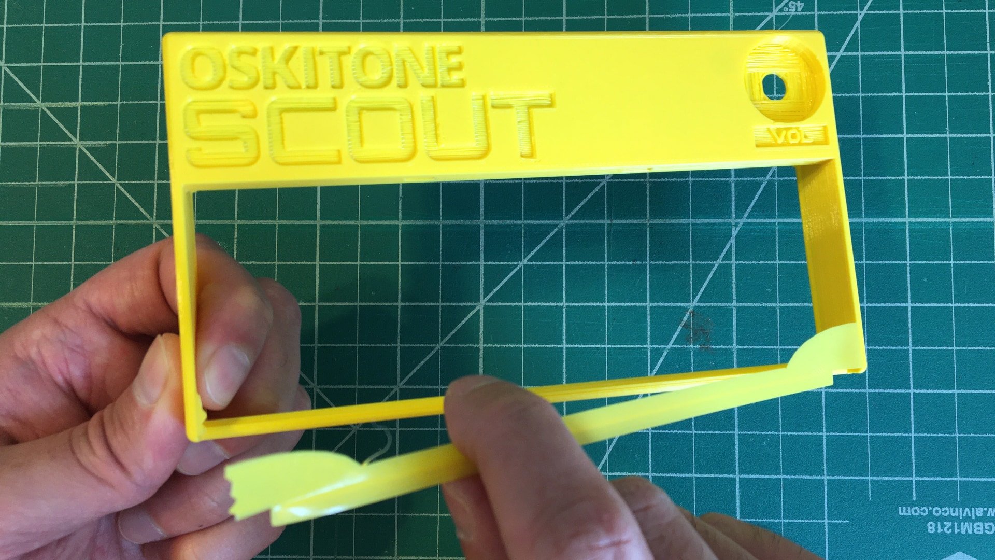
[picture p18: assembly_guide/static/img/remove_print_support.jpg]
Snap off support on enclosure top


## Test fit before soldering

:::note
Optional, but it's a good idea to confirm the printed pieces are sized correctly now rather than after you're done soldering!
:::

Try as many of these as you have patience for. All should be tight fits, doable with just your hands and without any pliers or other tools. (Take a sneak peek at the [Final Assembly](final-assembly.md) step if any are unclear.)

* Insert volume potentiometer shaft into its **knob**'s cavity.
* Pop the speaker into its circular cavity on the **enclosure bottom**.
* Glide the keys mount rail onto its aligners on the **enclosure top**.
* Try snapping the two **enclosure** halves together. It's an intentionally tight fit; be brave!

If any pieces don't fit, verify the printed dimensions match what you expected as visualized in your slicing program. Revisit the slicing information in the [3D-Printing Parts and Slicing](3d-printing-parts-and-slicing.md) section.

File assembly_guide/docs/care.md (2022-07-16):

---
id: care
title: Care
sidebar_label: Care
---

- 3D-printed plastic is susceptible to warping under hot temperatures. Keep it out of prolonged direct sunlight.
- When the Scout seems to reset randomly while playing (or doesn't turn on at all!), that's a sign that its 3 AAA batteries don't have enough voltage. [Open up the enclosure](opening-the-enclosure.md) and replace them.

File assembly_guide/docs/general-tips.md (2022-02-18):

---
id: general-tips
title: General tips and getting started
description: Things to keep in mind as you solder your Scout. Take your time and be patient!
sidebar_label: General tips and getting started
image: /img/scout_assembly-16-420-8-128.gif
slug: /general-tips
---

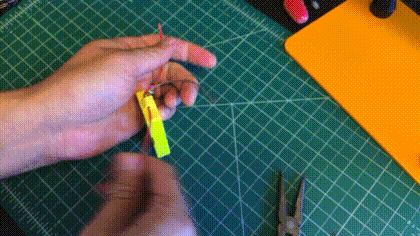
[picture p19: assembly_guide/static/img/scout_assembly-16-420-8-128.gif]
Timelapse of soldering and assembling a Scout (https://vimeo.com/586501851)


:::note
Take your time and be patient! If you run into a problem, try to keep a cool head and refer to the [PCB troubleshooting](pcb-troubleshooting.md) section. If your problem remains unfixed and you can't figure it out, [please _email_ me to let me know](https://www.oskitone.com/contact)! I'll do my best to help you, and your feedback will help improve the guide and other future Oskitone designs.
:::

## General tips

- **Component colors**<br />
  This guide's components' brands and body colors (and even the PCB color itself) may look different from yours, and that's okay! What's important is that the part types and values are in the right spots.
- **Resistors are labeled with colors, capacitors with numbers**<br />
  Resistors' values are marked as colored bands on their body. Ceramic capacitors use a number system to denote their value.
- **Ceramic and electrolytic capacitors**<br />
  There are two kinds of “caps” used in this kit. Ceramic capacitors are small, circular, and have no polarity; they can be placed in either direction. Electrolytic caps are bigger, cylindrical, and have marked +/- polarities.
- **IC chips are static-sensitive**<br />
  The included IC chips can be damaged by static electricity. Leave them in their packaging until ready to install. Before handling, discharge any static electricity on your body by touching a large piece of metal. You can even use an anti-static mat and/or wrist strap for extra caution.
- **ICs in sockets**<br />
  Each IC chip comes with a corresponding socket with the same number of pins. You will solder the socket to the PCB, not the chip itself. This prevents overheating the IC with the soldering iron and makes it easier to switch a faulty one out.
- **Component polarities**<br />
  LEDs, batteries, and electrolytic capacitors have positive and negative leads. Where applicable, the PCB will be labeled where each lead goes or a component outline to denote orientation.
- **IC orientation**<br />
  The IC chips also have an orientation, marked by a notch at their top. Make sure these line up when soldering the sockets and again when inserting the chips. A chip can be permanently damaged if inserted incorrectly!
- **Get tricky/sticky with short-lead components**<br />
  Components with short leads can be hard to get to stay on the PCB, because you can't really bend their leads to get them to stay put. But there are tricks! Try using tape or "Blu-Tack" adhesive to hold them. Or clip the solder into your "holding hands", and try bringing the _board to the solder_ (instead of the typical reverse of solder to board).

## Let's get started!

For reference, we'll end up with something like this when we're done:



### How this guide is organized

Each group of steps in the Scout's assembly has a test at the end to make sure everything you just did is working as expected, ie: "Make sure the LED lights up", "Make sure the microcontroller works", "Make sure the speaker has sound", etc.

If it doesn't work, don't fret! Look over the [PCB troubleshooting](pcb-troubleshooting.md) tips. Don't move on in the instructions until you've got the test working.

:::note Note for the experienced/impatient
The guide's steps are intentionally ordered. If you don't want to follow the guide, that's okay! But it may be harder to debug later if anything doesn't work as expected.
:::

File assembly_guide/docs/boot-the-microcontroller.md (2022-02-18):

---
id: boot-the-microcontroller
title: Boot the microcontroller
description: How to get the Scout's microcontroller working and booted up.
sidebar_label: Boot the microcontroller
image: /img/pcb_assembly/030400@0.5x.jpg
slug: /boot-the-microcontroller
---

## Steps

1. Solder capacitors **C1** (220uF) and **C2** (.1uF, marked 104), oscillator **Y1**, and resistors **R2** (220, Red Red Brown) and **R5** (10k, Brown Black Orange).
   - **C1** has polarity. Match its white side to the white side of its footprint.
   - **Y1** has three legs and no polarity.
2. Solder **U1** socket. It will have a dimple at one end, which should match the footprint on the PCB.
   - Solder two pins on opposite sides and verify the socket is perfectly flat before soldering the rest. If it's not and you try pushing it in, you can accidentally pop out a pin &mdash; not good!
3. With the power off, carefully insert **ATmega328**. It will have a dimple (and/or a small dot in a corner), which should match the socket.

## Test

Turn the power switch back on, and the LED should blink a new, different color a couple times. This lets you know that the ATmega is booted up and ready. Power off.

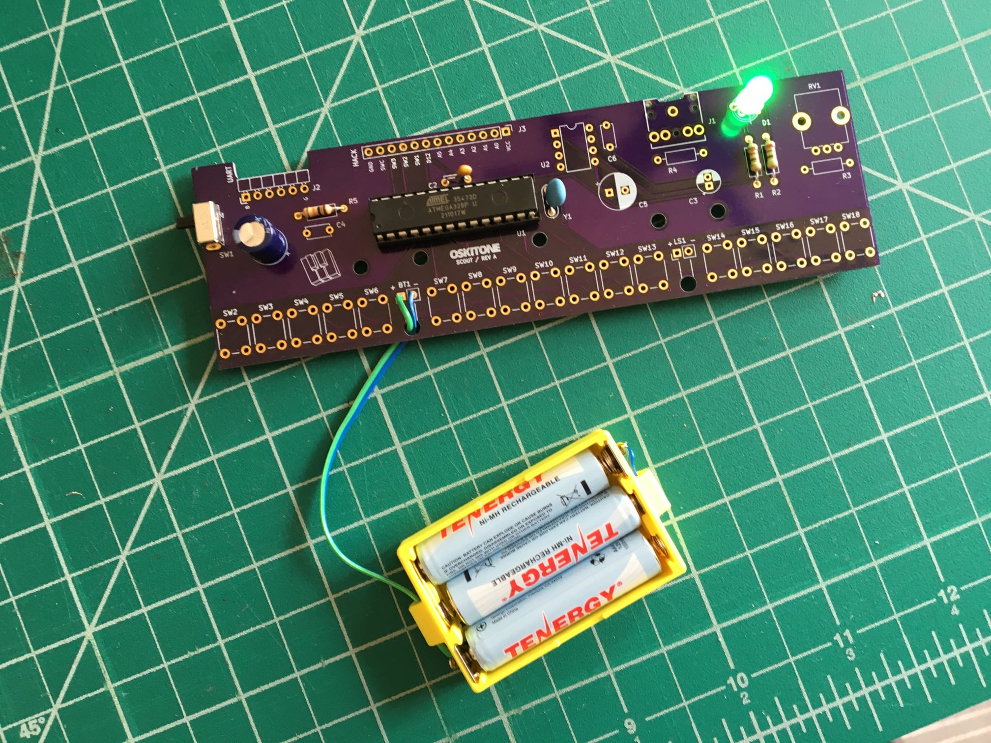
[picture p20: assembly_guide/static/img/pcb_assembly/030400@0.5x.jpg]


Not working as expected? Check the [PCB troubleshooting](pcb-troubleshooting.md) section. Otherwise, continue to the next step.

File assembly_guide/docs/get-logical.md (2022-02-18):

---
id: get-logical
title: Get logical
description: Test the microcontroller's logic!
sidebar_label: Get logical
image: /img/pcb_assembly/040200@0.5x.jpg
slug: /get-logical
---

:::note
Take your time and make sure the switch is perfectly flat against the PCB before soldering all of its pins.
:::

## Steps

1. Solder an SPST switch to **SW2**.
   - **_Make sure the switch is absolutely flat against the PCB before soldering all of its pins._**
   - One way to do this is to solder one pin to hold it in place, then use one hand to push it into the PCB while melting the solder with your other hand; if there's any gap there it should pop in. Visually inspect to make sure it's good, then repeat with the pin on the _opposite corner_. Then inspect and do the remaining pins. It takes time but is worth it.

## Test

With power on, press the switch. The LED should light just like it does on boot! Power off.

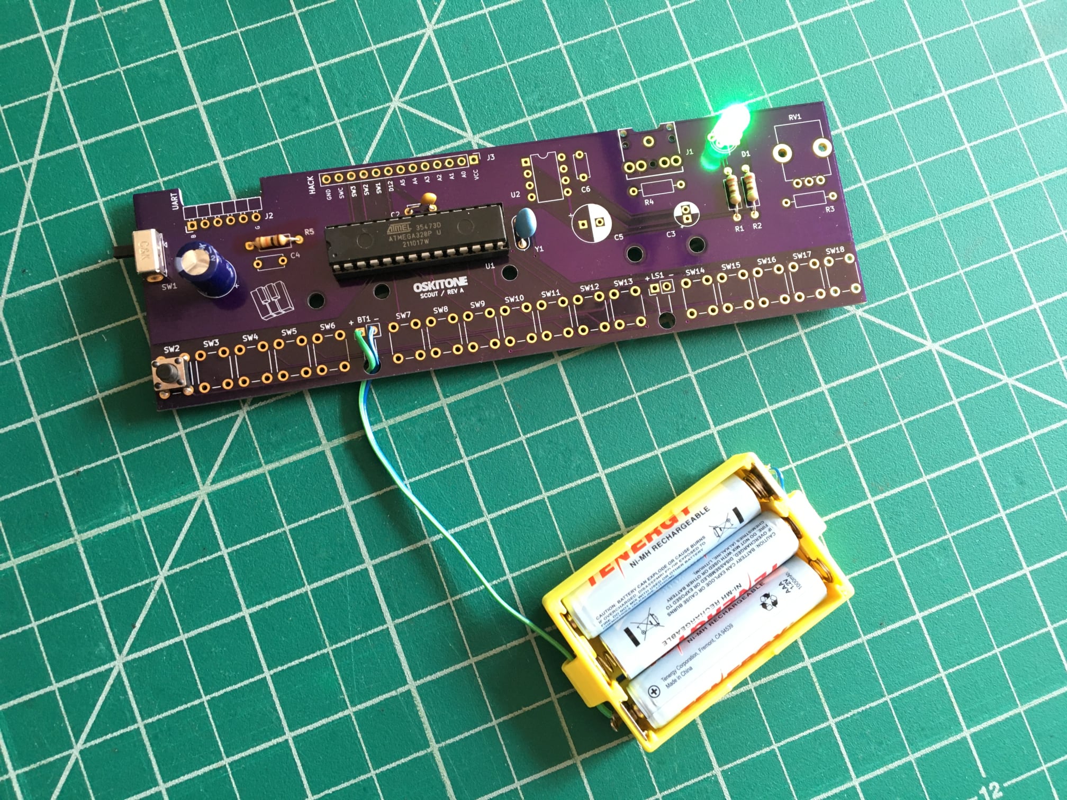
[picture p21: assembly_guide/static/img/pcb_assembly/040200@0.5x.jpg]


Not working as expected? Check the [PCB troubleshooting](pcb-troubleshooting.md) section. Otherwise, continue to the next step.

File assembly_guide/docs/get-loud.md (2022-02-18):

---
id: get-loud
title: Get loud
description: How to solder the Scout's amp to, you guessed it!, get loud.
sidebar_label: Get loud
image: /img/pcb_assembly/060500@0.5x.jpg
slug: /get-loud
---

## Steps

1. Solder capacitors **C5** (220uF) and **C6** (.1uF, marked 104) and resistor **R4** (1m, Brown Black Green; resistor body may be blue in your kit).
   - Make sure **C5**'s polariy matches its footprint, just like **C1**.
2. Wire speaker to **LS1**.
   1. Thread remaining ribbon cable through hole.
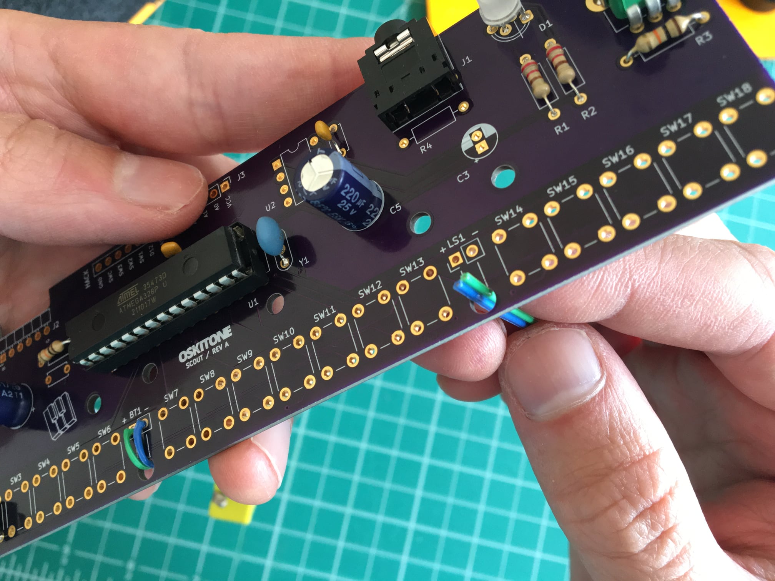
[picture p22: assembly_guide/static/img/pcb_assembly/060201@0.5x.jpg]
      
   2. Strip insulation and solder to **LS1**.
   3. Strip and solder the other ends to the speaker, matching the "+" and "-" sides.
3. Solder socket **U2**. Match its dimple to the footprint, just like **U1**.
4. With the power off, carefully insert **LM386** chip, again making sure its inserted the correct way.

## Test

Power on, unplug your headphones, and press the switch. It should be playing out of the speaker now. Power off.

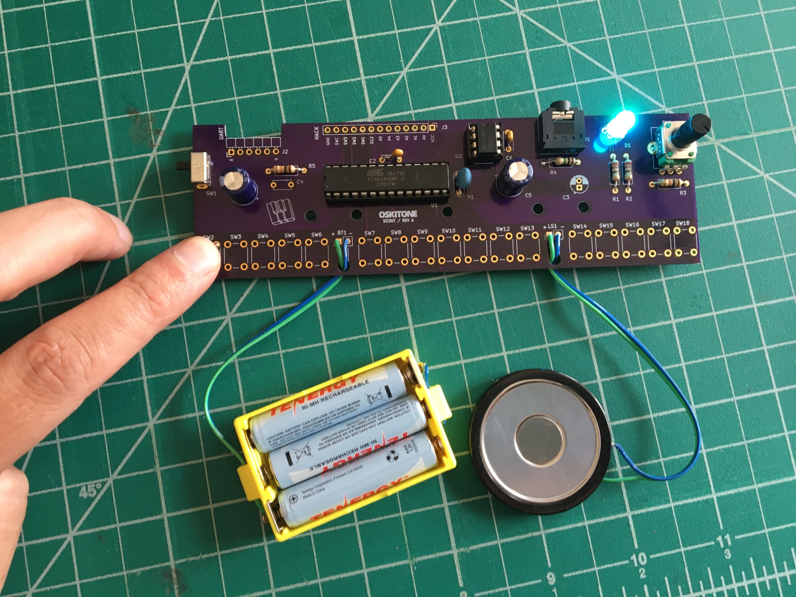
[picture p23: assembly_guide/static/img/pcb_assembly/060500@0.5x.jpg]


Not working as expected? Check the [PCB troubleshooting](pcb-troubleshooting.md) section. Otherwise, continue to the next step.

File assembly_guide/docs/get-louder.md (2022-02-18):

---
id: get-louder
title: Get louder
description: Not loud enough for ya? Get LOUDER.
sidebar_label: Get louder
image: /img/scout_assembly-16-420-8-128.gif
slug: /get-louder
---

## Steps

:::note
Optional. Skip if it's already loud enough for you (or whoever you're giving it to)!
:::

1. Solder cap **C3** (1uF).
   - Match polarity.

## Test

Power on and press some switches. The speaker should be louder now! Power off.

Not working as expected? Check the [PCB troubleshooting](pcb-troubleshooting.md) section. Otherwise, continue to the next step.

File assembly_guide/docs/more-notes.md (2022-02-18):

---
id: more-notes
title: More notes
description: Add the rest of the Scout's note buttons.
sidebar_label: More notes
image: /img/pcb_assembly/070200@0.5x.jpg
slug: /more-notes
---

:::note
Take your time and make sure the switches are perfectly flat against the PCB before soldering all of their pins.
:::

## Steps

1. Solder the remaining tactile 16 switches, **SW3** through **SW18**.

We want them all as flat against the PCB as **SW2**, so take your time here and verify as you go. When done, they should all line up _perfectly_.

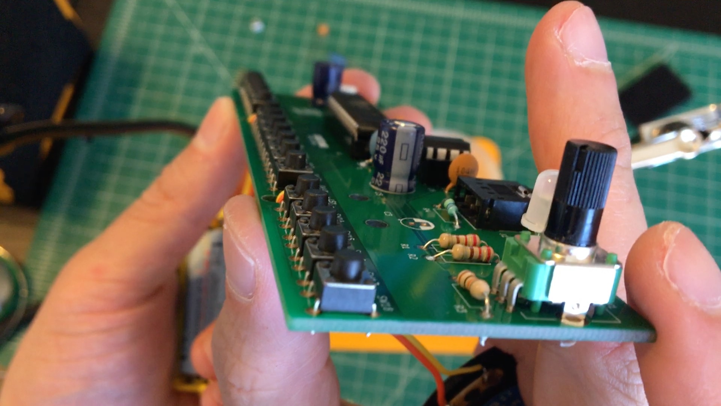
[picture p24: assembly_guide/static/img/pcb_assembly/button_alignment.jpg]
button alignment


If they don't line up perfectly as pictured above, you'll have problems later with some notes playing accidentally when the enclosure snaps together.

## Test

Power on and press each. They should all play different notes out of the speaker. See if you can play a little tune! Power off.

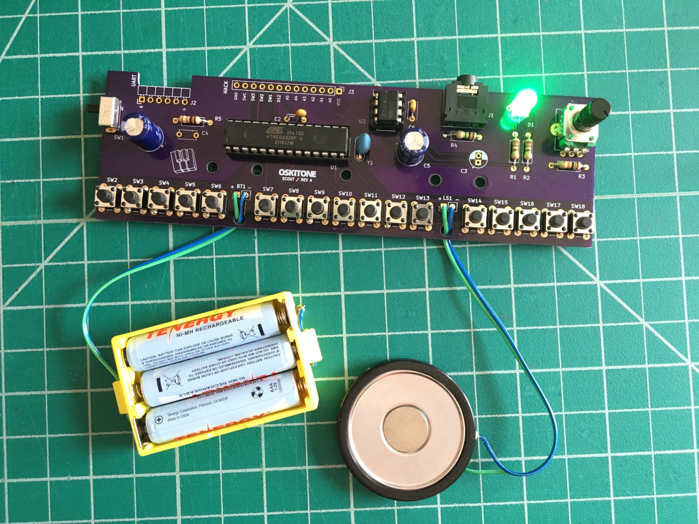
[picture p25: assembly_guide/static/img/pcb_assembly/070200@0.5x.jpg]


Not working as expected? Check the [PCB troubleshooting](pcb-troubleshooting.md) section. Otherwise, continue to the next step.

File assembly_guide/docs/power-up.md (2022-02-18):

---
id: power-up
title: Power up
description: Getting power to Scout's PCB and toggling an LED.
sidebar_label: Power up
image: /img/pcb_assembly/020400@0.5x.jpg
slug: /power-up
---

## Steps

1. Solder LED at **D1**
   1. The LED has four pins for three different colors plus ground. The longest one is to ground and it goes to the hole that has a line coming out of it.
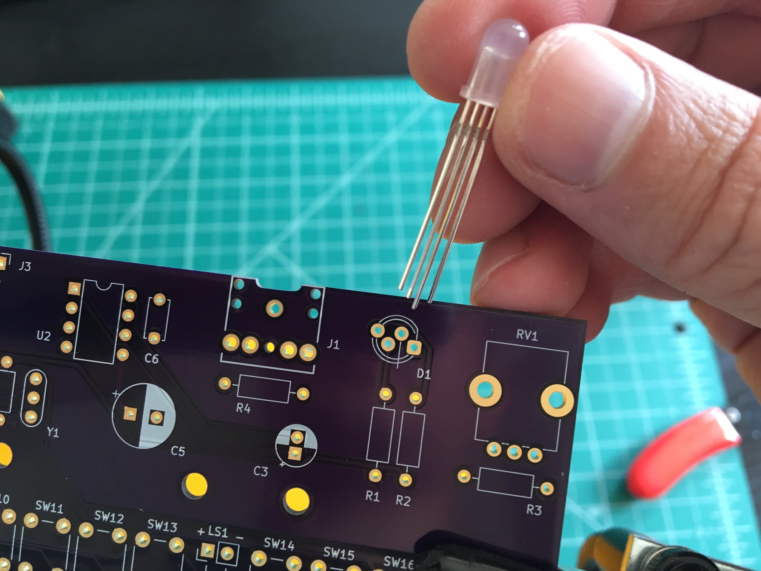
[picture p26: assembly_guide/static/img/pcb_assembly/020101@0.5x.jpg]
      
   2. Get the LED as vertically close to the PCB as reasonable; it doesn't have to be flat against PCB but does need to be straight up and down -- no leaning!
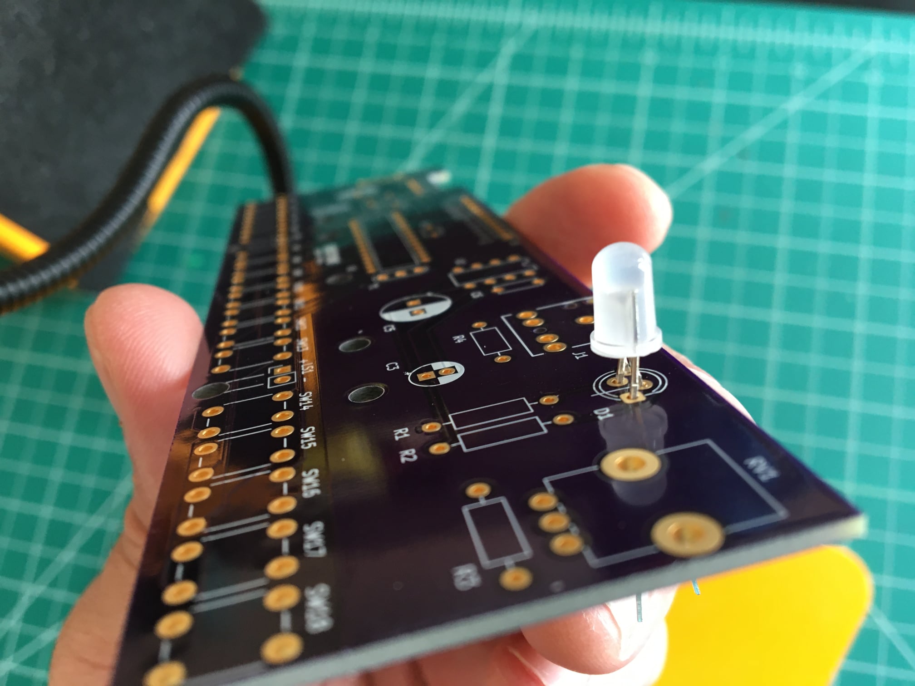
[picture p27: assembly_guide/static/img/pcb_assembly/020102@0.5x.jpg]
      
2. Solder sliding toggle switch **SW1** and resistor **R1** (220, Red Red Brown).
   - Make sure the switch is flat against the PCB and its actuator is pointing left, away from the PCB.
   - You can use a bit of tape or "Blu-Tack" adhesive to hold the switch in place as you solder.
3. Wire battery pack to **BT1**
   1. Thread the other side of the ribbon cable connected to the battery pack up through the hole near **BT1**, then strip and solder in place. Make sure the "+" and "-" wires are going to the right places.

## Test

Add the batteries back. Toggling **SW1** should now light one color of the LED! Yes, it is bright!! Power off before continuing soldering.

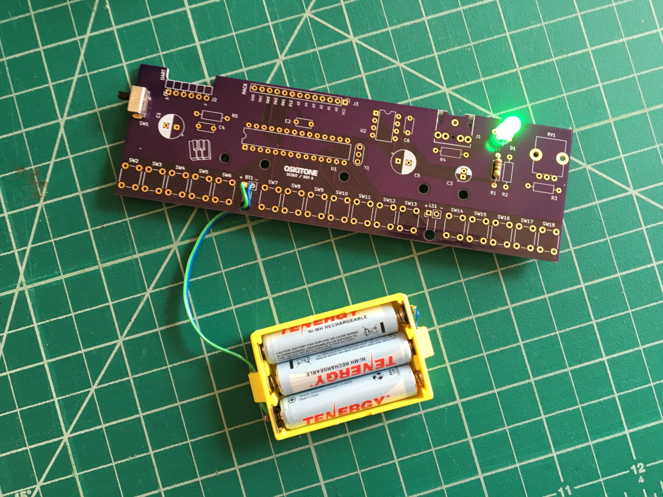
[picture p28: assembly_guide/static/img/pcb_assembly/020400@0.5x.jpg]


Not working as expected? Check the [PCB troubleshooting](pcb-troubleshooting.md) section. Otherwise, continue to the next step.

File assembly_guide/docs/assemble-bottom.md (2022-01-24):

---
id: assemble-bottom
title: Assemble bottom
description: How to assemble the Scout bottom, after soldering is done.
sidebar_label: Assemble bottom
image: /img/final_assembly/switch_clutch.jpg
slug: /assemble-bottom
---

:::note
You're almost done! Take your time to follow the directions in order.

And check out the [Assembly troubleshooting](assembly-troubleshooting.md) section if you run into any trouble.
:::

## Steps

### 1. Speaker

Pop the **speaker** into its circular cavity on the **enclosure bottom** with the speaker's shiny side up.

speaker

### 2. Battery holder

Pop the **battery holder** into its cavity in the middle of the **enclosure bottom**.

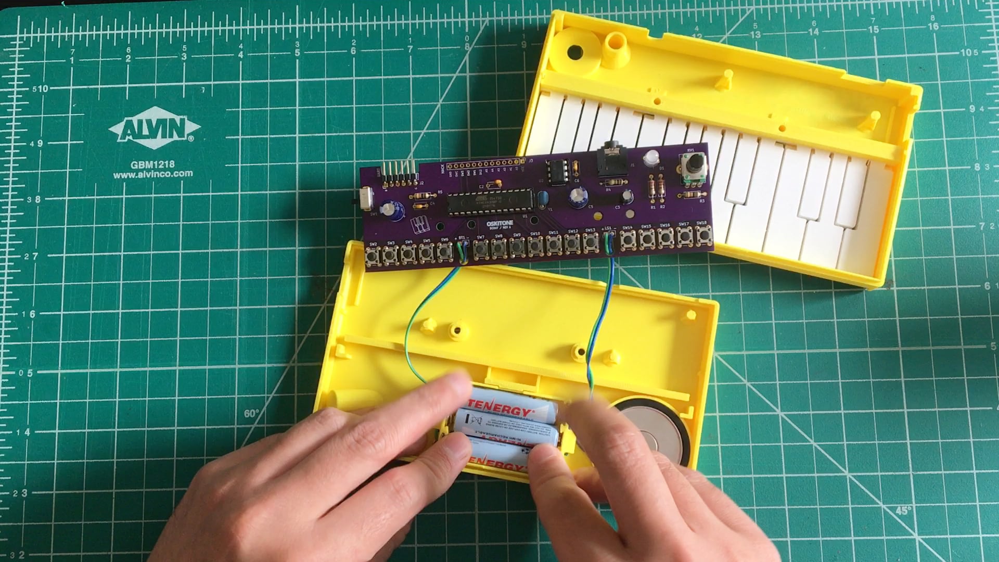
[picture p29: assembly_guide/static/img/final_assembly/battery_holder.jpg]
battery_holder


### 3. PCB

Insert **PCB** onto the **enclosure bottom**, nestled into its aligners.

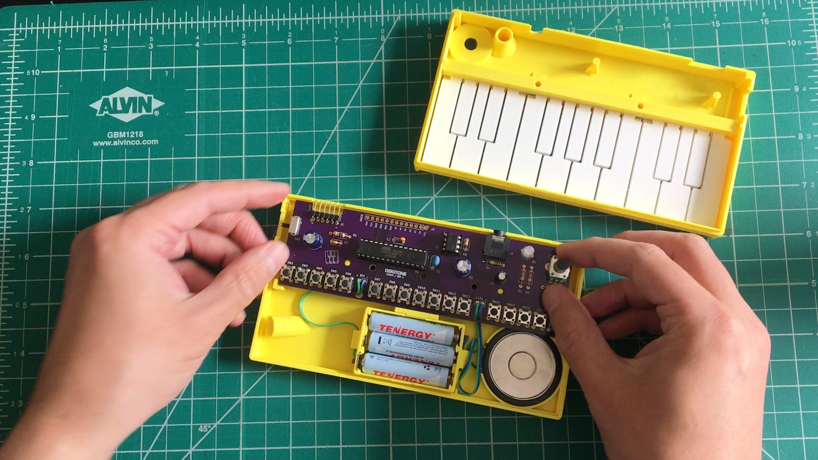
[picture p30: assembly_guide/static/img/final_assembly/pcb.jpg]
pcb


Orient the wires so that they're relatively contained within the space there and won't poke up into where the keys will be.

### 4. Switch clutch

Add the **switch clutch** into its spot around the switch.

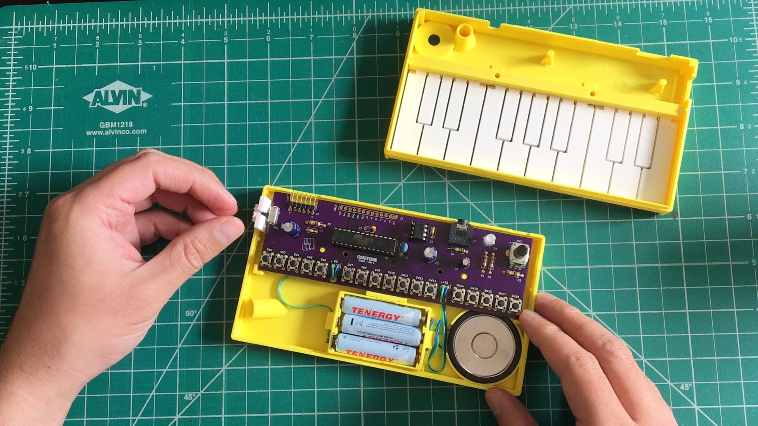
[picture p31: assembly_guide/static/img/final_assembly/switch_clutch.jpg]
switch_clutch


This piece is vertically symmetrical, so either way is fine.

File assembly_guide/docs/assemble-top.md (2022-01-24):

---
id: assemble-top
title: Assemble top
description: How to assemble the Scout top, after soldering is done.
sidebar_label: Assemble top
image: /img/final_assembly/keys_mount_rail.jpg
slug: /assemble-top
---

:::note
You're almost done! Take your time to follow the directions in order.

And check out the [Assembly troubleshooting](assembly-troubleshooting.md) section if you run into any trouble.
:::

With the PCB done soldering and working, it's time to finish the job! Let's put the rest together, and we'll start with the top.

## Steps

### 1. Nuts

Slide **square nuts** into nut locks on **enclosure top**. It'll be snug, but they'll fit! Use needle-nose pliers or a similar tool to push them in until their holes line up with those on the enclosure.

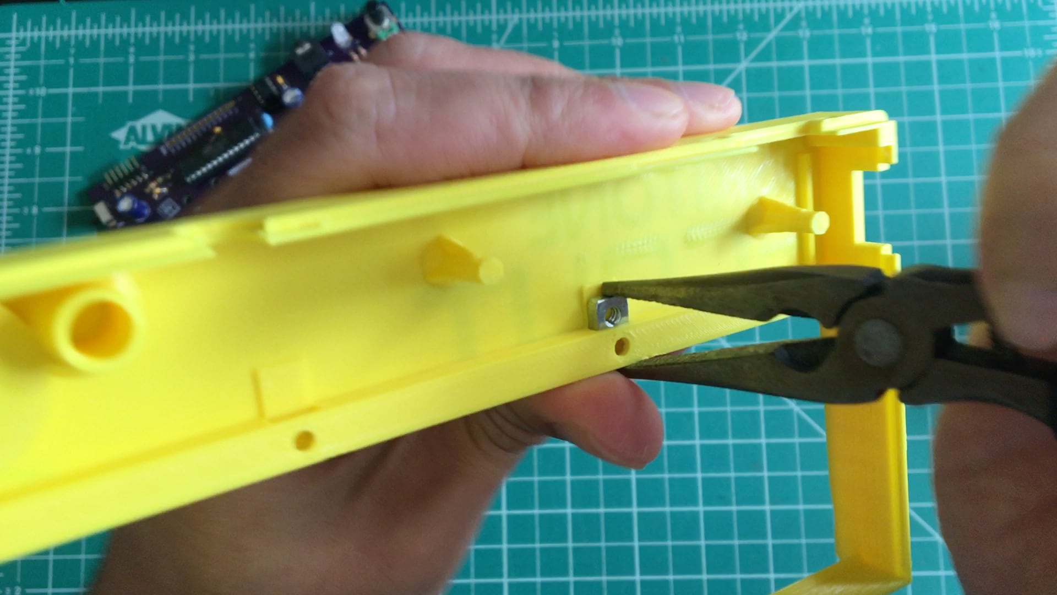
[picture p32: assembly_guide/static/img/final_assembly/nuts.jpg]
nuts


### 2. Keys

This part can be a little tricky and is easy to mess up, so let's first take a look at a cross section of how the **keys** fit into the **enclosure top**:

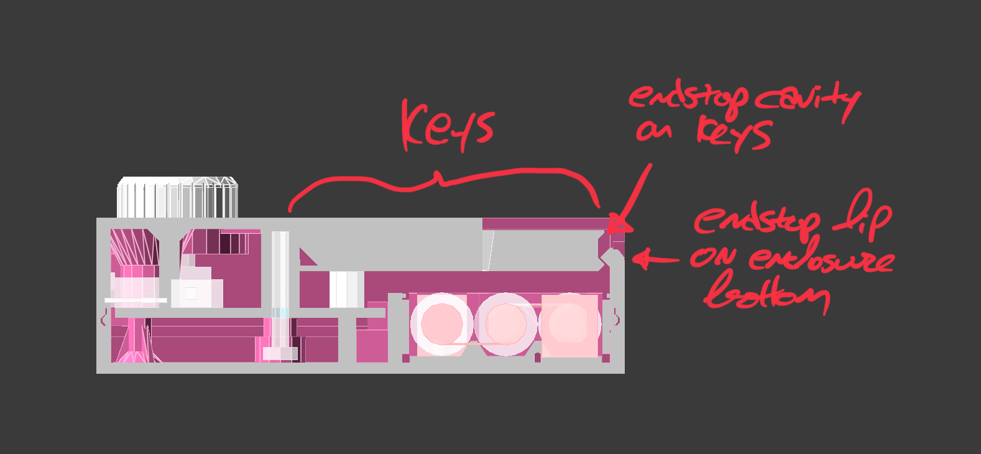
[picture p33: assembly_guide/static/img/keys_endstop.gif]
Cross section of the Scout with keys endstop annotated


Notice a couple things:

1. The front of the **keys** (on the right side of the above picture) have an endstop cavity.
2. That cavity fits onto matching endstop lip on the **enclosure top**.
3. Those two together prevent the keys from being pressed too far down or being pulled up.

Add the **keys**. Its rail has cavities on the sides that fit into matching aligners  on the **enclosure top**.

keys

It'll take some careful wiggling, but your goal is to guide the keys down _onto the aligners and into the endstop_.

When done, view the keys from the side and confirm none of them are visibly held down. Then test that the endstop is working correctly by pushing the keys _both up and down_ &mdash; they shouldn't be able to travel too far.

Here's a video showing exactly what that looks like:

<p><iframe src="https://player.vimeo.com/video/668413823" width="640" height="360" frameborder="0" allow="autoplay; fullscreen" allowfullscreen></iframe></p>

:::caution
Don't move on until this looks good!
:::

### 3. Keys mount rail

Glide the **keys mount rail** onto its aligners. Don't worry if it seems a little warped &mdash; it will be held flat by the screws.

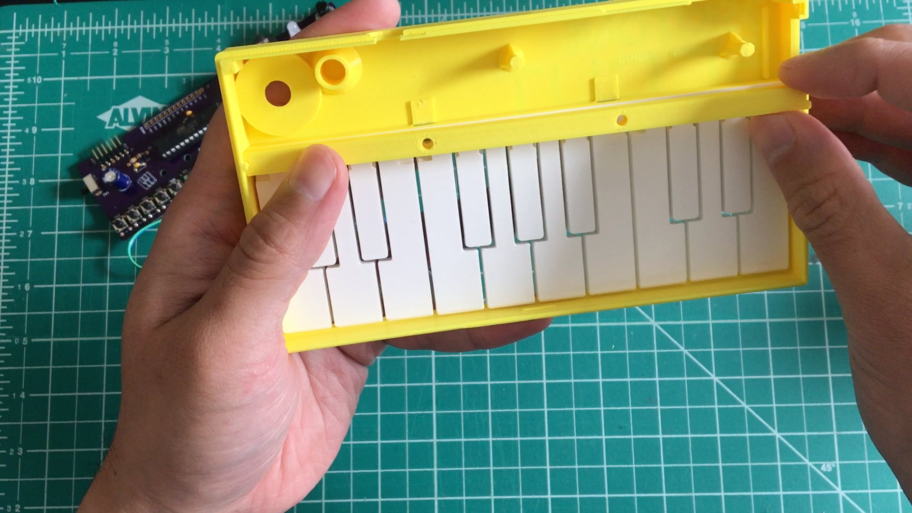
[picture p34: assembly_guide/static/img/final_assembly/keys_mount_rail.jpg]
keys_mount_rail


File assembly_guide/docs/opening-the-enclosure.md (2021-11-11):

---
id: opening-the-enclosure
title: Opening the enclosure
description: How to open up the Scout enclosure after it's snapped together.
sidebar_label: Opening the enclosure
image: /img/scout_assembly-16-420-8-128.gif
slug: /opening-the-enclosure
---

Later, when you need to change the batteries (or maybe just want to admire your hard work!), you'll need to open the enclosure back up.

1. Unscrew bottom **machine screws**. They don't have to come all the way out, just loosen.
2. Pop off the volume **knob**. A flathead screwdriver (or similar tool) may help provide leverage.
3. Insert that same flat tool on the UART cavity or the horizontal gap on the back right, then wedge the enclosure apart.

<p><iframe src="https://player.vimeo.com/video/589544440" width="640" height="360" frameborder="0" allow="autoplay; fullscreen" allowfullscreen></iframe></p>

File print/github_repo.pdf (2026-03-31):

3D-printed, Arduino-compatible, 17-key mono synth. Squeeeee!

www.oskitone.com/product/scout-synth

Languages

OpenSCAD 87.3% (https://github.com/oskitone/scout/search?l=openscad) | Shell 5.5% (https://github.com/oskitone/scout/search?l=shell) | C++ 4.7% (https://github.com/oskitone/scout/search?l=c%2B%2B) | JavaScript 1.4% (https://github.com/oskitone/scout/search?l=javascript) | CSS 1.1% (https://github.com/oskitone/scout/search?l=css)

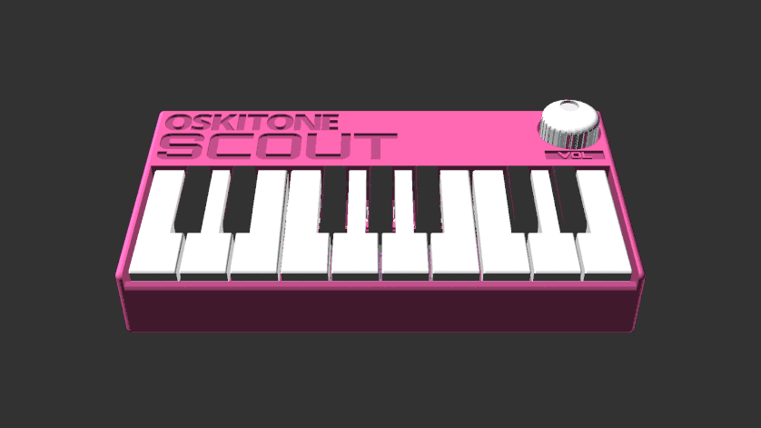
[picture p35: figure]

scout (/skout/):

1. One sent to obtain information
2. Jean Louise “Scout” Finch, of Atticus Finch
3. The first synth from Oskitone to venture into the big ol' world of microcontrollers

The Scout is:

Beginner-friendly: All components are through-hole (instead of surface mount) for easier soldering, and full assembly takes about 45min. Standalone, battery-powered, doesn't need a computer or external speakers to work. Fun! 3D-Printable: Besides the electronics and nuts and bolts, all parts are 3D-printed. And with a total width of ~160mm (about 6.3"), the Scout can fit on smaller, "Mini" (18x18x18cm) size print beds.
Hackable: Arduino-compatible and fully open source! Hook up an FTDI Serial TTL-232 cable (https://www.adafruit.com/product/70) (sold separately) to update its code using the Arduino IDE.

# Scout

Minimally featured: 1.5 octaves of keys, a volume knob, on/off switch, speaker, headphone jack. Monophonic square wave with fixed glide and octave.

In addition to it being the first microcontroller-controlled instrument from Oskitone, the Scout would also make a fine introductory DIY instrument for the budding electronics hobbyist. (Some experience soldering and a general familiarity with how electricity works are recommended though!)

As such, it is intentionally minimal, with the goal of the shortest possible time from starting the kit to making music with it. No MIDI/CV or other IO, as is. If you're looking for a full-featured studio instrument, this ain't it, bub! :)

Demo: https://vimeo.com/587660426
Purchase a kit: https://www.oskitone.com/product/scout-synth-diy-electronics-kit
Assembly guide: https://oskitone.github.io/scout/
Blog post: https://blog.tommy.sh/posts/scout/

The Scout's 3D-printed models are written in OpenSCAD.

Assumes poly555 and apc repos are in a sibling directory and are both up to date on the main branch. Here's how I've

You'll also need to install the Orbitron (https://fonts.google.com/specimen/Orbitron) font.

STLs are generated with make_stls.sh . Run ./make_stls.sh -h for full flags list.

September 6, 2021: Loosen knob fit on pot shaft (6cce7a7)
August 9, 2021: Init (9b5ffe5)

To develop, cd assembly_guide then npm run start .

Designed by Oskitone. Please support future synth projects by purchasing from Oskitone. (https://www.oskitone.com/)

Creative Commons Attribution/Share-Alike, all text above must be included in any redistribution. See license.txt for additional details.

## 3D Models

### Dependencies

### Building

### Changelog

## Documentation

## License

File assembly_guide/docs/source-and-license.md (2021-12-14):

---
id: source-and-license
title: "Source and License"
description: The Scout is open-source hardware.
sidebar_label: Source and License
image: /img/scout_assembly-16-420-8-128.gif
---

## Source

The Scout is open-source hardware.

[https://github.com/oskitone/scout](https://github.com/oskitone/scout)

## License

> Designed by Oskitone. Please support future synth projects by purchasing from [Oskitone](https://www.oskitone.com/).
>
> Creative Commons Attribution/Share-Alike, all text above must be included in any redistribution. See license.txt for additional details.

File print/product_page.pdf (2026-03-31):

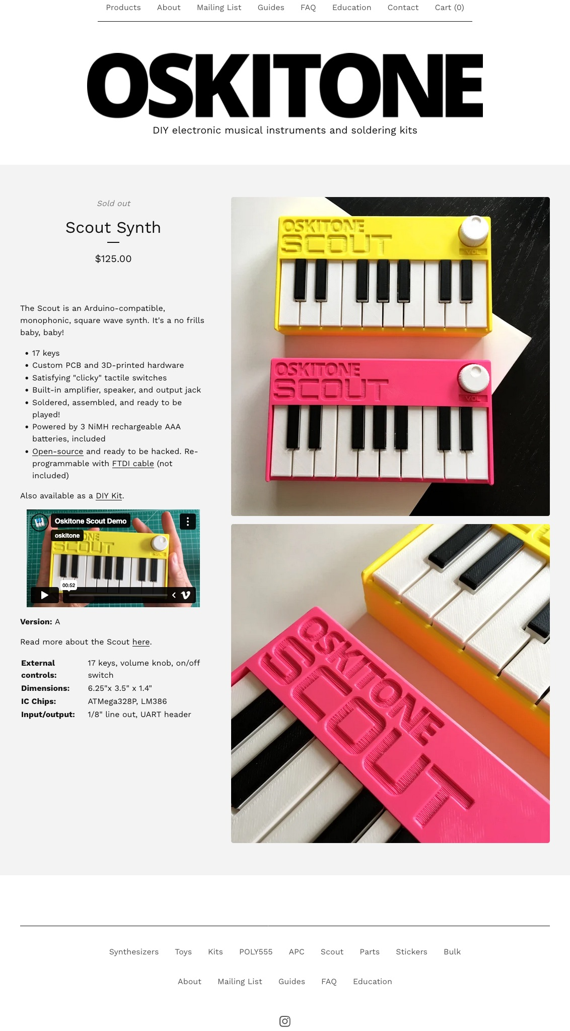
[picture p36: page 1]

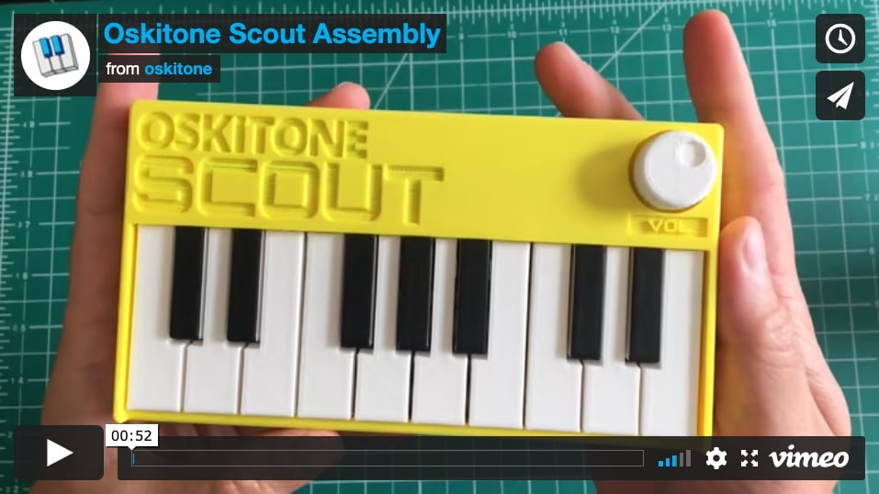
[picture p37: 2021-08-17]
assembly_guide/static/img/video.jpg

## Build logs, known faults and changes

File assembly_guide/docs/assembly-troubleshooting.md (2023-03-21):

---
id: assembly-troubleshooting
title: Assembly troubleshooting
description: Common problems that come up when assembling the Scout.
sidebar_label: Assembly troubleshooting
image: /img/scout_assembly-16-420-8-128.gif
slug: /assembly-troubleshooting
---

- If the screws are hard to insert into the enclosure bottom, don't force them but look to see if the **keys mount rail** is in the way. It may have come loose from its aligners.
- Key problems
  - A note is stuck on?
    - The key mounting screw(s) may be too tight. With the Scout turned on, try loosening the screw until the note turns off.
    - The next thing to check is if the front lip of the enclosure top is bending inwards, catching and holding a pressed key. If that's the case, try gently bending the lip back outwards until the parts no longer catch each other. You can also try trimming the plastic back with a utility knife.
  - A note needs to be pushed really far down to play? Or it turns off when pressing another near it? The key mounting screw(s) may be too loose. Try tightening!
  - The speaker/battery wires can sometimes get in the way of keys, making them difficult to actuate. [Pop the enclosure apart](opening-the-enclosure.md) and see if you can make them lay flatter.
  - Most other key problems are from some obstruction between the key piece and the enclosure. Read through the ["Assemble top"](assemble-top.md#2-keys) section again and verify everything looks correct.
- If the volume knob is hard to press onto its pot shaft, don't force it -- that could permanently damage the potentiometer. Try filing the inside of the knob's shaft cavity. If printing at home, make sure you've got the most recent STL models.

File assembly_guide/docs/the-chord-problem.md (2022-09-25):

---
id: the-chord-problem
title: The chord problem
description: Sometimes playing specific chords
sidebar_label: The chord problem
image: /img/scout-10-838-032.gif
slug: /the-chord-problem
---

The Scout is monophonic; it can only play one note at a time. If you try to hold multiple notes simultaneously, it tries to do what's called "last note priority" and only plays the most recently held key's note.

But sometimes, specific chords or sets of keys seem to add a note that you hadn't anticipated.

## Reproduce the issue

1. Play the first three white keys individually in succession. **C**, then **D**, then **E**. They should sound exactly as you'd expect.
2. Now, play them together. **C** _and_ **D** _and_ **E**.
3. Notice that it plays a totally different note at the end there instead of **E**. If you continue playing keys up individually, you'll discover that we got an **F#** at the end instead of the E we were expecting.
4. Now play the same run of those first three white keys but in the reverse order. **E** _and_ **D** _and_ **C**.
5. Again, notice that the third note at the end is **F#**.

Super weird, right? Why is this happening?

## Debugging with the serial monitor

If we [log out the indexes of the buttons](change-the-arduino-code.md#serial-debugging) being pressed and play **C**, **D**, **E** individually it looks like this:

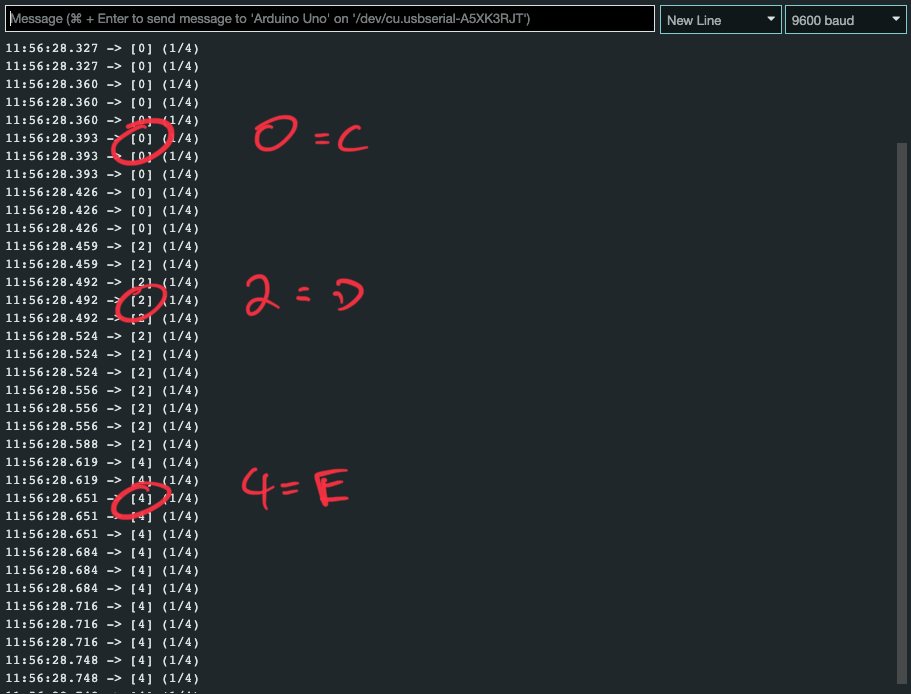
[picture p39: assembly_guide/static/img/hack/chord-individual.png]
Screengrab of the Arduino serial monitor while playing C, D, and E individually


Makes sense. **0** is **C**, **2** is **D**, and **4** is **E**. That's just what we expected! (In code, we order lists starting at 0 instead of 1, so the indexes of the list of 17 keys go from 0 to 16, not 1 to 17.)

But holding them together looks like this:

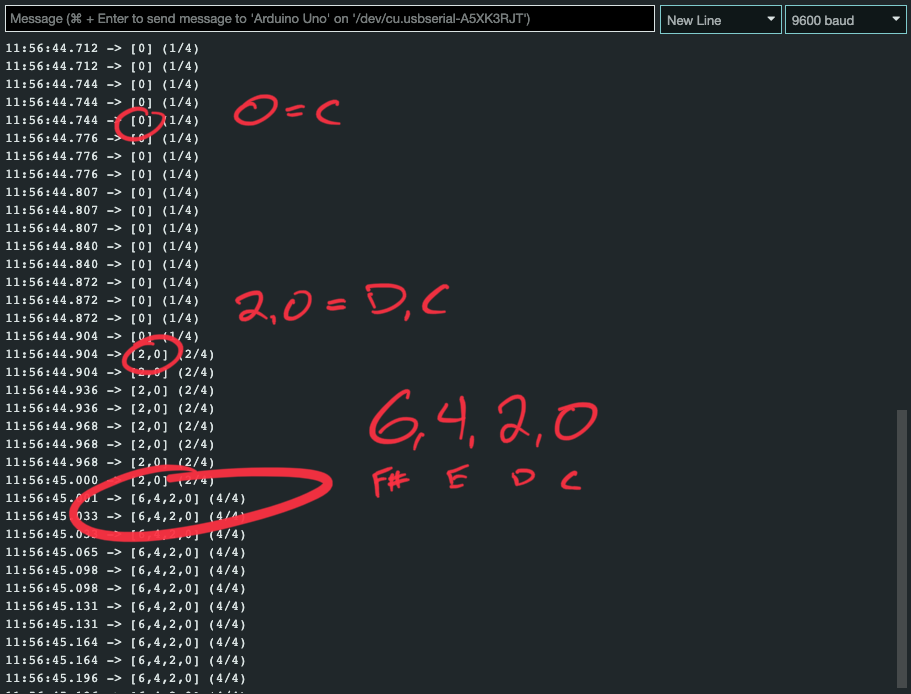
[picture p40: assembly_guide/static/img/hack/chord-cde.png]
Screengrab of the Arduino serial monitor while playing C, D, and E together


The **0**, **2**, **4** are in there (reverse ordered but that's irrelevant) but we also see a fourth index, **6**. That's the index of the **F#** key.

Playing and holding **E**, **D**, **C** is the same with a different order:

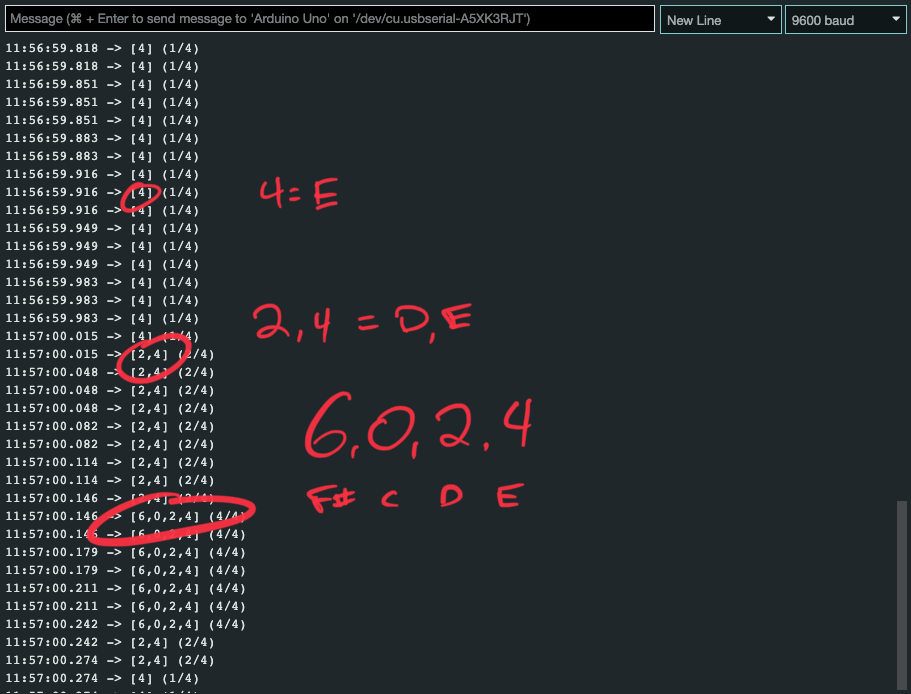
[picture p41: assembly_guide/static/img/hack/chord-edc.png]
Screengrab of the Arduino serial monitor while playing E, D, and C together


That doesn't solve our problem, but it does tell us that the microcontroller is indeed interpreting that the **C**, **D**, and **E** keys are being pressed but, for some reason, incorrectly _adding_ the **F#**.

## Checking the schematic

### A matrix of keys

The Scout has 17 keys but they only take up 9 pins on the ATmega328. It does this by convincing the microcontroller that the 17 keys are arranged in a matrix of rows and columns: 4 rows \* 5 columns = 20 possible keys.

When a key is pressed and its switch closes, the pins for its row and column connect.

The matrix of rows and columns with the notes labelled, read from top to bottom and _then_ left to right:

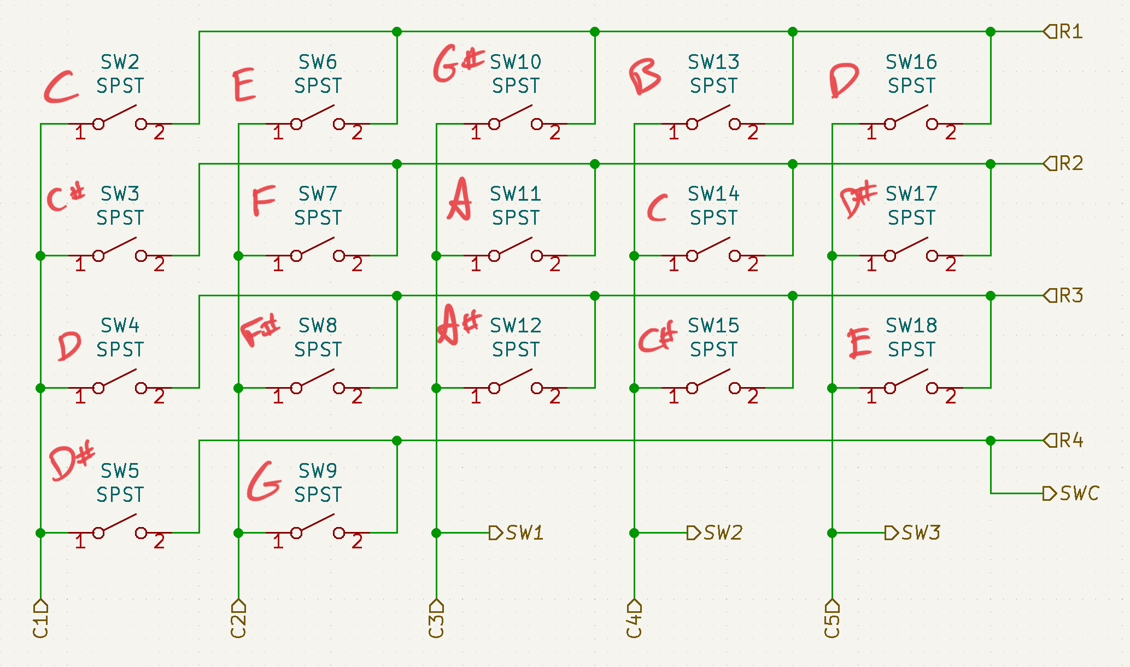
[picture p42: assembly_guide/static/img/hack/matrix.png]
Matrix schematic with switches labelled to their corresponding notes


- **Note 1:** The ATmega328 only has 14 digital input/output (IO) pins, which wouldn't be enough for all the keys if they were wired individually. There are other ways besides a matrix to get more IO out of our chip but they all require soldering more components.
- **Note 2:** The 3 remaining, unused matrix spots in the bottom right are available for use on the ["HACK" header](change-the-arduino-code.md#pins).
- **Note 3:** Awkwardly, the hardware components for the notes are indexed from SW2 to SW18, because only the code uses zero-indexing and the on/off switch was SW1. Thankfully, at least they are still in linear order!

### Connecting rows and columns

We can see that **C** is **R1C1** (Row 1, column 1), **D** is **R3C1**, and **E** is **R1C2**.

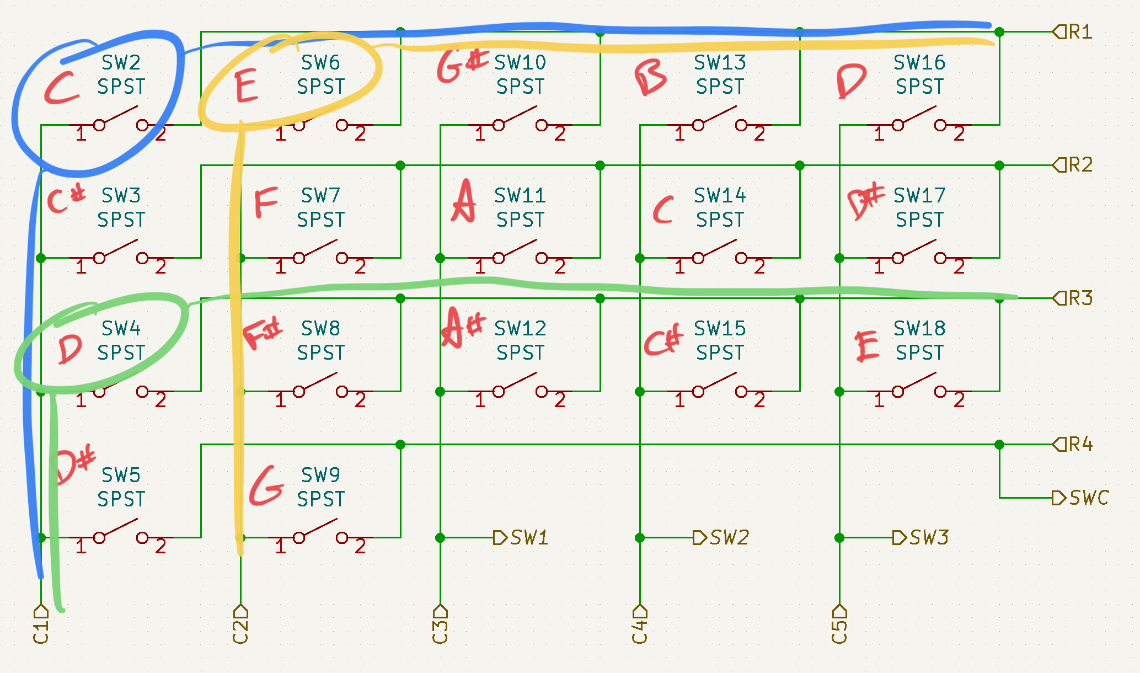
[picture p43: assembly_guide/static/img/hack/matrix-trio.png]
Matrix schematic with C, D, and E matrix points highlighted


But to the microcontroller, it also sure looks like you're pressing **F#** at **R3C2**. I mean, how could it know you're not? So it just throws it in there.

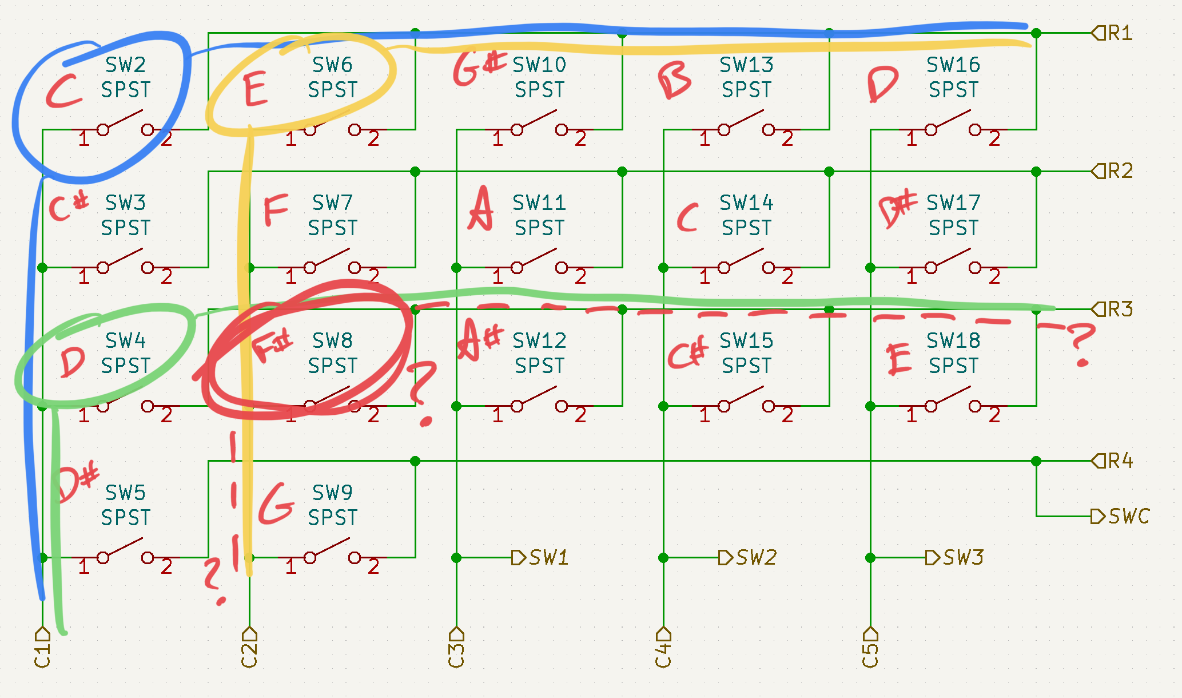
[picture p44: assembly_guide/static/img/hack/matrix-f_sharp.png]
Matrix schematic with C, D, and E matrix points highlighted


That's the culprit!!

## Is it a bug?

Issues like this "chord problem" are normally avoided on more complex matrix circuits like your computer keyboard with diodes along the switches, but these were ommitted on the Scout to cut down on kit cost and assembly time. The Scout's monophony was an intentional limitation to deter encountering it. After all, _it is supposed to be simple instrument_!

So it's _kind of_ a bug but _more_ like a "known issue" and a cost to be paid for the simplicity of the Scout's assembly.

### Homework

Looking at the matrix schematic, can you find other key combinations that will have the "chord problem"?

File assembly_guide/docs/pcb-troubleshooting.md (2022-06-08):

---
id: pcb-troubleshooting
title: PCB troubleshooting
description: Common problems that come up when soldering the Scout PCB.
sidebar_label: PCB troubleshooting
image: /img/scout_assembly-16-420-8-128.gif
slug: /pcb-troubleshooting
---

## General tips

Any of these problems can cause a variety of "just not working right" errors in a circuit. Familiarize yourself with these troubleshooting checks and do them regularly.

- Turn the PCB over and check all solder joints. A majority of problems are caused by insufficient or errant soldering. Familiarize yourself with what a good joint looks like in the [Adafruit Guide To Excellent Soldering](https://learn.adafruit.com/adafruit-guide-excellent-soldering).
- Are all chips in the right orientation? Each has a notch/dimple that should match the footprint outline on the PCB.
- Do the batteries have enough power? The three batteries should have a total voltage of 3.6 to 4.5 volts. If the Scout seems like it's restarting a lot as you play it, that's a good sign the batteries need replacing.

## Specific issues

- If there’s buzzing, check for any metal scraps stuck to the speaker’s magnet.
- If some keys are touchy or behaving weird, check to see that their switches are inserted all the way and perfectly flat against the PCB. (See also: the "Key problems" section in [Assembly troubleshooting](assembly-troubleshooting.md))
- If multiple keys seem to be tied to the same note, there's probably a short (an accidental connection between soldering points) somewhere. Check all joints as described above, then try cleaning the bottom of the PCB with isopropyl alcohol. Leftover flux and resin from the soldering process _can_ be conductive!
- If you're hearing an unwanted hum from the speaker when the Scout isn't being played, verify all .1uF caps are soldered well. It may also be from noise added by long wires, so do use the recommended wire lengths in this guide.

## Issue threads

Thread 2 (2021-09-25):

avrdude content mismatch verification error

thedeany, 2021-09-25:
I'm attempting to upload the `scout.ino` file from this repo, and upon doing so I receive a `avrdude: verification error; content mismatch` error. It also says
```
avrdude: verification error, first mismatch at byte 0x0327
         0xbf != 0x9f
```
but the `0x0327` and `0xbf != 0x9f` values change every time I upload, even if I've not changed anything in the `scout.ino` file.

The sketch _does_ appear to upload (I can hear my changes on the Scout when I play it), but the error persists. I just wanted to note it here in case anyone else comes across it and doesn't think to try playing the Scout after uploading to realize it actually worked. Also noting it here in case I'm doing something wrong or there's some other fix 😄

Arduino IDE 1.8.16 on macOS 11.6
Using a [HiLetgo FT232RL FTDI Mini USB to TTL Serial Converter](https://www.amazon.com/gp/product/B00IJXZQ7C/ref=ppx_yo_dt_b_search_asin_title?ie=UTF8&psc=1) (which I've used on other projects) instead of the cable mentioned in the README.

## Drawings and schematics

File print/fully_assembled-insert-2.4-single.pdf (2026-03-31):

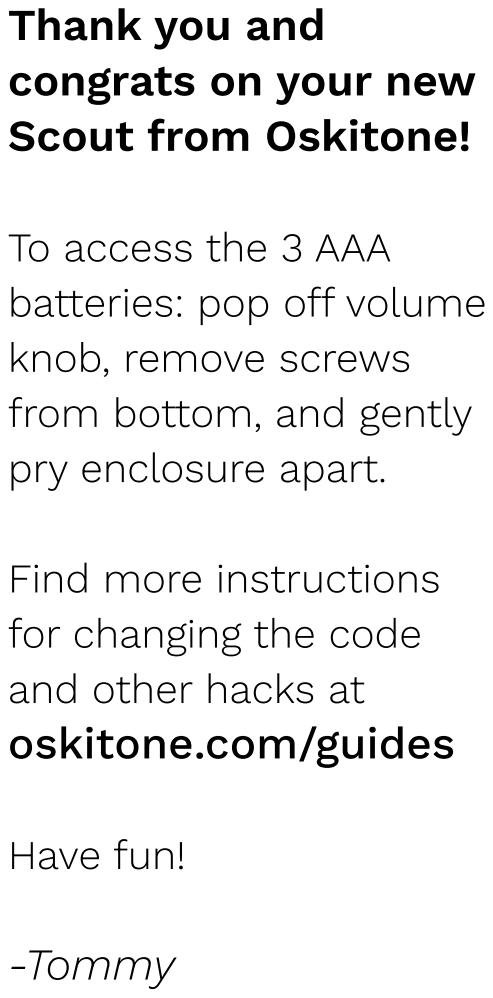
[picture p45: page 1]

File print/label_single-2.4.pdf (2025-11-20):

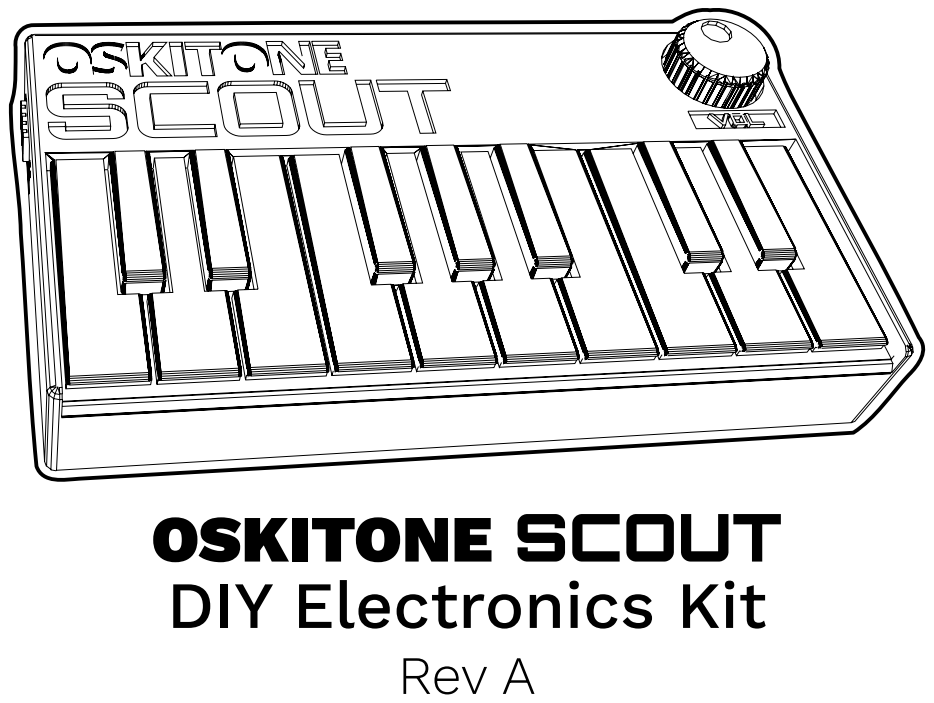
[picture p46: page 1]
Rev A

OSKITONE SCOUT
DIY Electronics Kit

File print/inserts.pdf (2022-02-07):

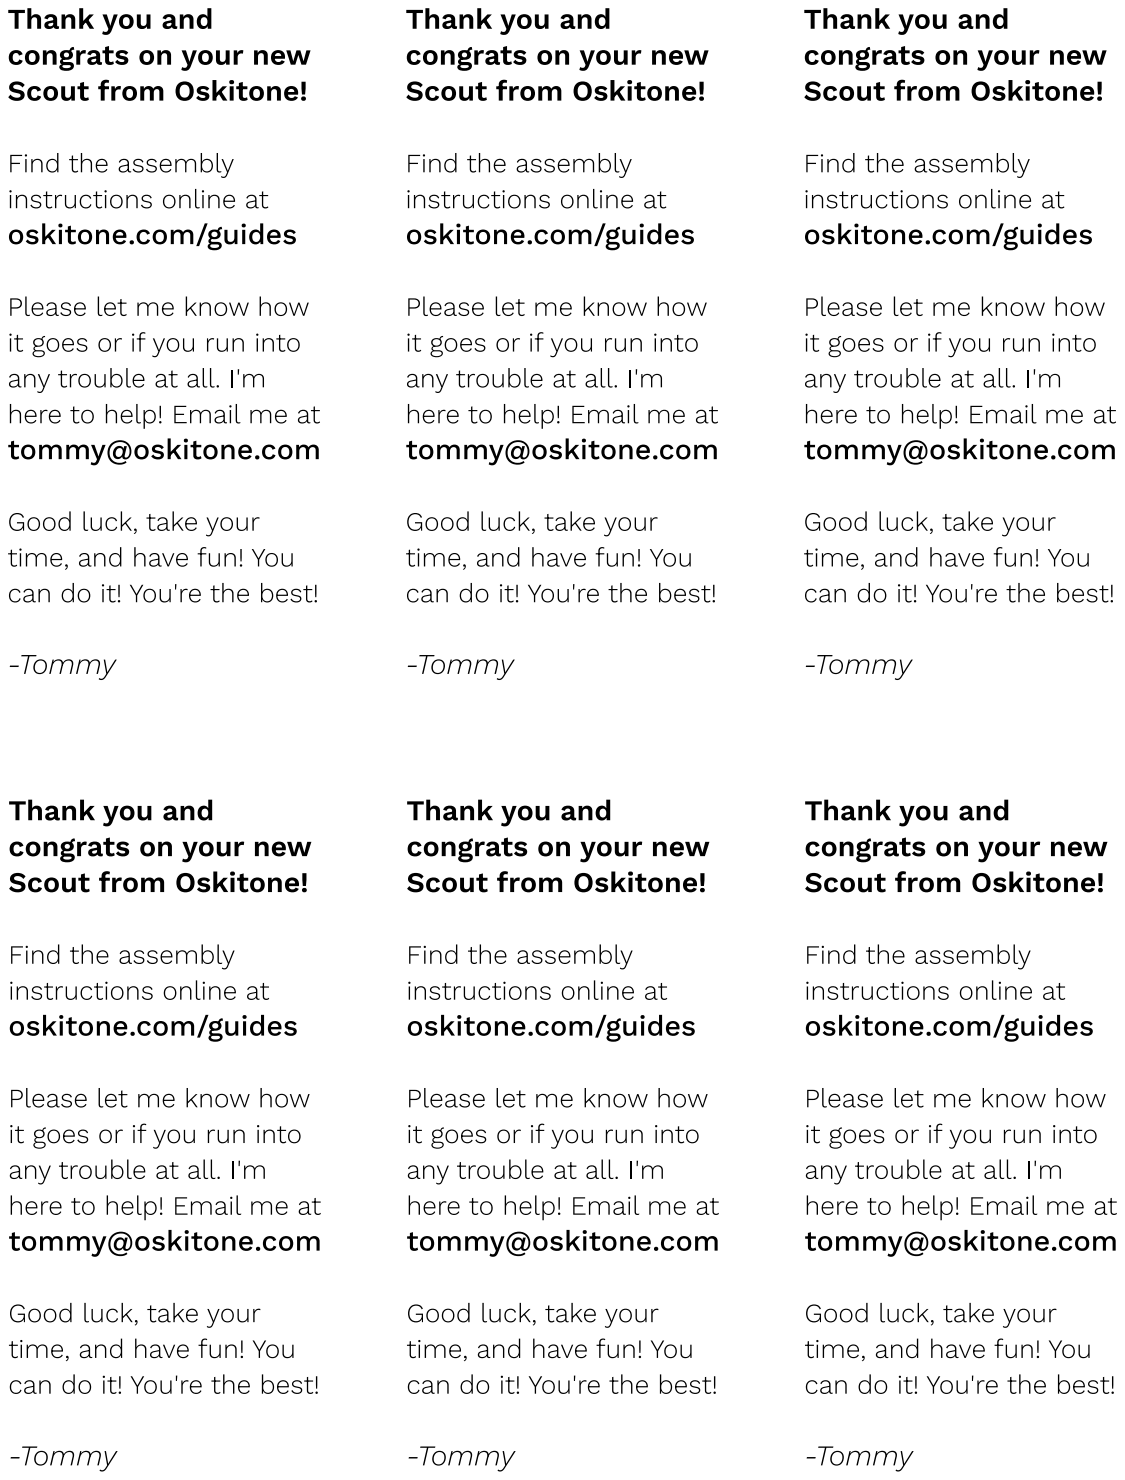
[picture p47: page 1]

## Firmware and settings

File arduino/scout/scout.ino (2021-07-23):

#include "Frequency.h"
#include "KeyBuffer.h"
#include "Notes.h"

// SETTINGS
int octave = 3;
float glide = .25;
bool glideOnFreshKeyPresses = true;
bool printToSerial = false;

const int CYCLES_PER_GLIDE_MAX = printToSerial ? 25 : 250;
const int STARTING_NOTE_DISTANCE_FROM_MIDDLE_A = -9;

const int SPEAKER_PIN = 11;

Notes notes(STARTING_NOTE_DISTANCE_FROM_MIDDLE_A);
KeyBuffer buffer;
Frequency frequency(glide, CYCLES_PER_GLIDE_MAX);

void blink(int count = 2, int wait = 200) {
  while (count >= 0) {
    digitalWrite(LED_BUILTIN, HIGH);
    delay(wait);
    digitalWrite(LED_BUILTIN, LOW);
    delay(wait);

    count = count - 1;
  }
}

void setup() {
  Serial.begin(9600);
  pinMode(LED_BUILTIN, OUTPUT);

  blink();
}

void loop() {
  buffer.populate();

  if (printToSerial) {
    frequency.print();
  }

  if (buffer.isEmpty()) {
    if (!glideOnFreshKeyPresses) {
      frequency.reset();
    }

    noTone(SPEAKER_PIN);
    digitalWrite(LED_BUILTIN, LOW);
  } else {
    frequency.update(notes.get(buffer.getFirst()) / 4 * pow(2, octave));

    tone(SPEAKER_PIN, frequency.get());
    digitalWrite(LED_BUILTIN, HIGH);
  }
}

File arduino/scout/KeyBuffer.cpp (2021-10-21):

#include "Arduino.h"
#include "KeyBuffer.h"

#define CIRCULAR_BUFFER_DEBUG
#include <CircularBuffer.h>
#include <Keypad.h>

const byte ROWS = 4;
const byte COLS = 5;
byte key_indexes[ROWS][COLS] = {
  {1, 5, 9, 12, 15},
  {2, 6, 10, 13, 16},
  {3, 7, 11, 14, 17},
  {4, 8}
};
byte rowPins[ROWS] = {7, 8, 9, 10};
byte colPins[COLS] = {2, 3, 4, 5, 6};

Keypad _buttons = Keypad(makeKeymap(key_indexes), rowPins, colPins, ROWS, COLS);

KeyBuffer::KeyBuffer() {
  CircularBuffer<int, BUFFER_MAX> _buffer;

  const int KEYPAD_LIBRARY_MINIMUM_DEBOUNCE = 1;
  _buttons.setDebounceTime(KEYPAD_LIBRARY_MINIMUM_DEBOUNCE);
}

bool KeyBuffer::isEmpty() {
  return _buffer.isEmpty();
}

bool KeyBuffer::isInBuffer(int c) {
  bool value = false;

  if (!_buffer.isEmpty()) {
    for (int i = 0; i < _buffer.size(); i++) {
      if (c == _buffer[i]) {
        value = true;
        break;
      }
    }
  }

  return value;
}

bool KeyBuffer::removeFromBuffer(int c) {
  int newStack[BUFFER_MAX - 1] = {};
  int newI = 0;

  bool hasRemoval = false;

  for (int i = 0; i < _buffer.size(); i++) {
    if (c != _buffer[i]) {
      newStack[newI++] = _buffer[i];
    } else {
      hasRemoval = true;
    }
  }

  if (hasRemoval) {
    _buffer.clear();

    for (byte i = 0; i < newI; i++) {
      _buffer.push(newStack[i]);
    }
  }
}

void KeyBuffer::populate() {
  bool isActive = false;

  _buttons.getKeys(); // populate keys

  for (int i = 0; i < LIST_MAX; i++) {
    byte kstate = _buttons.key[i].kstate;
    byte kchar = _buttons.key[i].kchar - 1;

    if (kstate == PRESSED || kstate == HOLD) {
      if (!isInBuffer(kchar)) {
        _buffer.unshift(kchar);
      }

      isActive = true;
    } else if (isInBuffer(kchar)) {
      removeFromBuffer(kchar);
    }
  }

  if (!isActive) {
    _buffer.clear();
  }
}

void KeyBuffer::print() {
  if (!_buffer.isEmpty()) {
    Serial.print("[");
    for (int i = 0; i < _buffer.size(); i++) {
      Serial.print(_buffer[i]);

      if (i < _buffer.size() - 1) {
        Serial.print(",");
      }
    }
    Serial.print(
      "] ("
      + String(_buffer.size()) + "/" + String(BUFFER_MAX)
      + ")"
    );
    Serial.println();
  }
}

char KeyBuffer::getFirst() {
  return _buffer.first();
}

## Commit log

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2021-01-10 Use keypad with fixed frequencies
    [scout.ino]
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2021-01-28 Fix first key priority
    When any key is held and another is pressed, the second note should
    play.
    But this wasn't working right for the first key, which would incorrectly
    keep priority.
    Bumping key_indexes seems to fix. Must've been something about that 0.
    IDK!
    [scout.ino]
2021-01-28 fixup! Fix first key priority
    [scout.ino]
2021-01-29 Increase octave range
    Swap switch for analog input
    [scout.ino]
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2021-04-08 Fix key mount nut locks
    [keys.scad]
2021-04-08 Fix screw head exposure DFM
    [enclosure_bottom.scad]
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2021-04-21 Improve glide
    * Control step with control, like pot
    * Tighten responsiveness by ditching frequency throttling and
    optionalizing Serial usage
    * Account for minor tolerance when "off"
    * Decouple glide amount from its step derivation
    And some unrelated stuff:
    * Guess at reasonable octave and glide
    [scout.ino]
2021-04-21 Fix settings leg on startup
    [scout.ino]
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2021-04-22 Flesh out Arduino clone schematic
    Should meet minimum running requirements now
    * Pull RESET into VCC
    * Add connector for FTDI Serial cable
    Tested w/ cornfieldelectronics usbcable, which I THINK is the same as
    Arduino's USBSerial and adafruit.com/product/70
    * Connect AVCC to VCC
    * Connect remaining RGB LED pins:
    * D13 to match Arduino
    * RX to watch for programming
    * Add TODOs:
    * lower voltage batteries to ditch 7805 and its caps
    * verifying pin22 to GND
    * ceramic resonator to ditch crystal caps
    [scout.sch]
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2021-04-24 Refine schematic before starting board layout
    * Add bypass caps
    * Do some schematic TODOs
    * Swap 9v and 7805 for 4.5v (3 AA or AAA batteries)
    * Swap crystal oscillator for ceramic resonator w/ built-in caps
    * Satisfy ERC by adding PWR flags
    * Switch to correct SPDT slider switch for power
    * Assign footprints
    [scout.sch]
2021-04-25 Draft PCB
    Very rough draft!
    * Swap volume pot to trimmer
    * Make header connectors bigger
    [scout.sch]
2021-04-26 Re-draft PCB
    * Move most stuff beyond mounting rail
    * Tighten mounting holes
    * Add text label
    * Confirm mount-to-button distance matches P5's accidentals'
    * Bring back big pot
    * Move switch to back of board and remove TODO
    * Add space for big cap to lay flat and remove TODO
    [scout.kicad_pcb, scout.sch]
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2021-04-27 Add amp
    I'd love to avoid it, but I don't think there's a way to get both
    safe headpone output _and_ drive a built-in speaker
    [scout.kicad_pcb, scout.sch]
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2021-04-27 Route
    * Fix audio jack pins
    * Add some TODOs to be done before buying
    [scout.kicad_pcb, scout.sch]
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2021-05-01 Provide fixtures to hold PCB in place
    [enclosure.scad, pcb_fixtures.scad]
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2021-05-03 Show and expose FTDI header
    * Tidy recurring translate stuff
    * Also reduce epsilon to debug why the pins didn't look centered
    Time for bed!
    [enclosure.scad, scout_pcb.scad]
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2021-05-07 Show screws and ensure they don't bite into enclosure top
    Looks like it's gonna be 3/4" screws, not 1" like the POLY555
    * Make nut_lock_floor an arg and fix its usage w/ nuts()
    * Derive screw_head_clearance and use it throughout
    * Fix "screw mount" cross section X so no other nuts obstruct view
    [enclosure.scad, nuts_and_bolts.scad, pcb_fixtures.scad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]
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2021-05-09 Refine enclosure half heights
    * Adjust enclosure half heights to obviate DFM for front key exposure
    * Try tongue-and-grooves to improve fit now that the top's front sides
    are no longer connected
    * Fix misused top_height vs bottom_height
    * Move key_lip_endstop onto now-taller bottom
    [enclosure.scad]
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2021-05-10 Make battery fixture a standalone holder component
    and hella rearranging
    [batteries.scad, battery_contacts.scad, battery_holder.scad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]
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2021-05-11 Revamp enclosure half heights
    * Parameterize enclosure fillet
    * Naively split enclosure half heights 50/50
    * Ditch tongue and groove for now
    * Fillet key exposure lip
    * Add DFM support for ^, now that top height is tall enough for it
    * Swap key_lip_endstop to other side yet again
    [enclosure.scad]
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2021-05-13 Reverse enclosure lips
    Hoping this will hold front key exposure lip (needs a better word!)
    in better
    * Add speaker fixture cavity so it won't collide with enclosure lip on
    other side
    * Tidy _keys_mount_alignment_fixture now that it's only used on one side
    [enclosure.scad, speaker.scad]
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2021-05-13 Refine key fit against enclosure
    * ~Tighten~ Remove tolerance between key and enclosure near mount
    Hopefully this removes some height gap between button actuators and
    keys, tho if it's too tight some will false trigger
    * Note some "rethink" thoughts on key_lip_endstop before I forget
    * Increase key travel so they don't collide with enclosure
    [enclosure.scad, key_lip_endstop.scad, keys.scad]
2021-05-13 Fix key_exposure_lip_support wall
    Because of some bad math, after filament-saving cavity, walls were too
    thin for slicer. This tries to fix that math AND increases
    BREAKAWAY_SUPPORT_DEPTH, which has historically been a little
    probelmatic anyway
    [enclosure.scad]
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2021-05-18 Thicken cantilever height to match POLY555
    Hopefully this will cut down on noise. Caveat is that the enclosure now
    needs to be sliggghhhtly taller, otherwise the nut juts into enclosure
    top.
    New min_screw_top_clearance arg ensures there's room for the screw to
    clear the nut, and its seemingly arbitrary value is to keep the derived
    cantilever_length at 4.6, which is what it was at before.
    Also added a TODO to try the cantilever_length from previous models,
    which are stored in constants for now.
    [keys.scad, scout.scad]
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2021-05-22 Refine LED exposure
    * Reposition to right, matching knob dimple
    * Recede, matching text engraving
    * Try to prevent light bleed w/ internal "shroud" chamfer
    * It's a heart!!!!
    [enclosure.scad, scout.scad]
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2021-05-26 Show key travel clearance
    and optionalize alongside PCB clearances
    [keys.scad, scout.scad]
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2021-05-31 Drop enclosure fillet in quick_preview
    Not needed for regular development, and its low $fn actually makes
    dev harder
    Also, try to fix pencil stand and engraving epsilons
    [enclosure.scad, enclosure_engraving.scad]
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2021-06-01 Refine enclosure fit
    * Increase bottom height to PCB Z
    * Loosen fit tolerance
    Not needed w/ screws or if/when tongue and grooves show up
    * Fix side engraving label Z
    * Remove PCB corner fixtures from enclosure bottom
    They were colliding w/ tray before, I think
    [enclosure.scad, pcb_fixtures.scad]
2021-06-01 Refine battery label engraving
    Previous was too small to print as designed
    [enclosure.scad]
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2021-06-08 Refine knob
    * Try a shorter profile
    * Try a tightened clearance for less wobble
    * Derive and use hub_ceiling (the height above pot shaft)
    [scout.scad]
2021-06-14 PCB rev _b (private B)
    * Increase mount length
    * Move, right-angle (same footprint), flip to front, and reverse switch
    * Move RGB LED, fix pin order, switch to easier footprint, and label GND
    * Move FTDI and headphone jack for better exposure
    * Add ICSP header
    * Expose remaining ATMEGA pins and matrix buttons for hacking
    * Add license, website, and plead
    * Test SVG silkscreens -- fun!
    * Mark relief hole to show which side it goes in
    * Polarize C3 (amp gain) from ceramic to electrolytic
    * Reverse volume direction
    [keyboard_matrix.sch, scout.kicad_pcb, scout.sch]
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2021-06-14 ~Hastily refine keystone_tabbed_contact cavities
    * Increase length to include lil tabs
    We'll see how this goes. Could be too long. Might also want to push
    them back so the front walls aline w/ their siblings
    * Add entry cavities
    These tabs have lil tabs (ugh, term overloaded now) that spring (ugh,
    again) and hold them into place, but they necessitate insertion in the
    opposite way! Anyway, this allows that.
    [battery_contacts.scad, battery_holder.scad]
2021-06-14 Keep refining tabbed battery cavities
    * Increase spring compression
    * Try reduced lil tab length
    * Swap contact tab side again
    * Try matched contact cavity depths
    * Eschew floor_cavity_height stuff for renewed _contact_tab_cavities
    that cut into the bottom instead of top
    * Seems like I might keep engraving passing through the floor, so let it
    do the chamfer stuff that bottom engravings do
    * Round outer walls with new fillet and $fn
    * Beef up wire tabs
    * Try simple wire relief holes
    [battery_contacts.scad, battery_holder.scad, enclosure.scad]
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2021-06-15 Estrange PCB and speaker
    * Move PCB back to not obstruct speaker
    * Reduce PCB Z to absolute minimum, accounting for battery
    * Decouple speaker Z from PCB Z (minimum for now...)
    * Derive key_length to fill new space
    * Fix enclosure height vs screw length math
    * Reduce pencil stand depth to not collide with keys
    [scout.scad]
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2021-06-16 Make it cute again
    * Bring back arbitrarily short key_length and its enclosure effects
    * Move speaker farther into corner and under PCB
    * Move PCB Z up to account for speaker
    * Ditch vestigial speaker_fixture_cavity now that it shouldn't obstruct
    enclosure lips
    [enclosure.scad, scout.scad]
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2021-06-17 Refine line out cavity
    * Add plug clearance (plug end wasn't as flush as I'd hoped, but this
    is a fine thing to do, even if it were)
    * Add a "valley" cavity for easier assembly
    * Fix rounding
    [enclosure.scad, scout.scad]
2021-06-17 Expand PCB enclosure top fixtures for new rev
    * Move back fixtures to not collide w/ components
    * Add back corners to make it obvious which side of enclosure
    the PCB should be inserted into
    * Extend the fixtures a couple mm beyond PCB for easier assembly
    too
    [pcb_fixtures.scad]
2021-06-17 Refine LED exposure
    * Strengthen chamfer shroud
    Print had a skipped layer and this part broke off
    * Ditch unused recession
    * Loosen cavity diameter and increase depth to PCB
    * Pop LED off PCB
    * Update intersection to be right in the middle of LED
    [enclosure.scad, scout.scad, scout_pcb.scad]
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2021-06-17 De-obstruct battery holder from PCB
    * Fix collision with PCB by dropping height to minimum
    Kinda related:
    * Increase wire relief width and fix Y math
    * Drop fillet in quick_preview
    [battery_holder.scad, scout.scad]
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2021-06-17 Fix battery holder hitch Zs extending beyond floor
    from mismatched $fn rounding
    [battery_holder.scad, scout.scad]
2021-06-17 Separate cantilever from its mounting end height
    No physical changes here but will allow
    * Experimenting w/ different cantilevers and their effects on
    playability w/o changing the enclosure dimensions
    * Increasing mounting end height to strengthen key lever fulcrum
    [enclosure.scad, keys.scad, scout.scad]
2021-06-19 Temporarily increase pot shaft diameter
    Until I have the correct pots back in stock
    [enclosure.scad]
2021-06-19 Abandon battery label engraving on back
    Not worth the hassle, given propensity for failure
    [enclosure.scad]
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2021-06-19 Try having enclosure bottom be PCB home
    * Move back corner fixtures to bottom
    * Adjust bottom height to avoid height_extension stuff
    * Rename _top/bottom_ modules for clarity
    [enclosure.scad, pcb_fixtures.scad]
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2021-06-19 Refine side engravings
    * Move up, closer to their cavities
    * Chamfer for DFM, prevent sagging ceiling
    [enclosure.scad, enclosure_engraving.scad]
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2021-06-22 Add PCB front corner fixtures too
    Totally fine now that PCB is on enclosure bottom
    [pcb_fixtures.scad]
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2021-06-23 Fix and improve PCB corner fixtures
    * Allow custom _fixture_pcb_difference Z
    * Decouple wall args and tidy coverage math
    * Remove floor from corner fixtures
    These were colliding w/ button pins and shouldn't be necessary anyway
    -- corners are for registration, not support
    * Add extra height to corners and ensure they can't collide w/ enclosure
    lip
    [pcb_fixtures.scad]
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2021-06-23 Reinforce key_exposure_lip_support
    Partially reverts commit 5f46c5fac1200d2b1205672a9aa945099ae243e7
    and increases the overlap between the side and front lip rafts
    [enclosure.scad]
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2021-07-04 Rethink PCB top fixtures on enclosure
    They don't need to connect to wall so that complexity can be removed.
    Make them match the stools on enclosure bottom, and chamfer all.
    [enclosure.scad, pcb_fixtures.scad]
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2021-07-04 Vertically center switch_clutch grip
    This makes the switch_clutch vertically rotatable and obviates problems
    caused by assembling it w/ the wrong orientation
    [enclosure.scad, scout.scad, switch_clutch.scad]
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2021-07-04 Reimagine how battery_holder fixes into enclosure
    * Arm -> nub: just 1, taller, and at top of holder
    * Bigger back hitch w/ wire relief, held down by PCB; ditch arm
    * Visualize PCB pin clearance to see it won't obstruct
    [battery_holder.scad, enclosure.scad, scout.scad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]
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2021-07-06 Refine battery_holder fixtures
    * Add back endstop
    * Increase side aligners size
    * Minor tidying
    [enclosure.scad, scout.scad]
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2021-07-06 Reverse battery_holder end terminals
    So the wires are more easily pointed left towards the PCB's pads
    [scout.scad]
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2021-07-07 Hide battery_contact tabs
    Don't need em poppin out of enclousure, and it's not worth the time
    to show them bent
    [battery_contacts.scad, scout.scad]
2021-07-07 Enable easy model centering for external scripts
    And parameterize quick_preview and flip_vertically to match
    [scout.scad]
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2021-07-09 Make key clearance realistic
    It doesn't drop down like an elevator, it slopes like a ramp
    [keys.scad]
2021-07-09 Deepen pencil stand
    As evidenced by 5f2415c7c0. Wow! I was missing a lot there...
    [scout.scad]
2021-07-09 Revert "Temporarily increase pot shaft diameter"
    This reverts commit 327795ce615001b322c772c0d55d79f51a344ebf.
    [enclosure.scad]
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2021-07-09 Try an even thicker ENCLOSURE_WALL
    The lip-cavitied enclosure bottom prints larger than the top, even when
    the wall is 3mm thick instead of 2.4mm.
    If a 4mm wall can't fix it, nothing will.
    [enclosure.scad]
2021-07-09 Move batteries back over to the left
    The wires will kinda collide with the battery_holder, especially as
    it's currently designed, but ultimately I think this mass should be
    distributed better and this is around where it ought to be.
    [scout.scad]
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2021-07-09 Revert "Try an even thicker ENCLOSURE_WALL"
    This reverts commit 22678f3799b917a781382b58c7ffe2c33da46899.
    This was damn near impossible to snap together, because the thicker
    walls had less "give" to bend. Makes sense!
    [enclosure.scad]
2021-07-09 Revert "HACK Increase enclosure_wall"
    I'm curious if this is till needed w/ longer snaps and the tighter
    battery_holder
    This reverts commit ff765d34d75f8599a576e091d13461a49bd08ba7.
    [enclosure.scad, keys.scad]
2021-07-09 Provide extra clearance for PCB stool registrations nubs
    [pcb_fixtures.scad]
2021-07-09 Tighten battery_holder back_endstop
    I want it to push the enclosure front + lip together. We'll see!
    [enclosure.scad]
2021-07-09 Strengthen PCB corner_fixture_wall
    Had one break. Let's get beefyyyyy
    [pcb_fixtures.scad]
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2021-07-09 Narrow snap width to fix messed up LINE placard
    [enclosure.scad]
2021-07-09 Move disassembly_wedge_cavity
    * Shorter and at top, so flathead sits exactly between the two halves
    * Moved to front and offset to side, to avoid T&G
    * Near batteries, which might be a nicer UX for when those need changing
    [enclosure.scad]
2021-07-09 Loosen enclosure tongue and groove fit
    Testing three things:
    * Will this help bottom concavity?
    * Are long groove snaps and pull enough to hold things together?
    * Halves should be a little easier to snap together?
    [enclosure.scad]
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2021-07-13 Re-tighten enclosure tolerance
    Answering the questions from commit b129b60e42:
    It did!
    No, sadly!
    Yeah!
    So this commit keeps the weaker pull (1x tolerance, not 2x) but brings
    tolerance to 1x instead of 2x. Some concavity is probably preferable
    to having any gaps between the halves.
    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
    [enclosure.scad]
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2021-07-13 Update PCB rev to _C (private C)
    * Fix RGB pins and swap R&G
    * Fix hacker header pin orders
    * Ditch programmer header
    * Add quieting resistor between amp and jack
    * Label headers
    * Move switch back
    * Move J2
    * Draw enclosure outline
    * Add more key mount holes
    * Ditch back silkscreen experiment
    * Ditch "Please support..." plea, for now
    * Echo out PCB dimensions and position
    * Add bypass cap for 386
    * Try OSKITONE branding
    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
    [pcb_fixtures.scad, scout.kicad_pcb, scout.scad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]
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2021-07-18 Ugh, split the difference on enclosure tolerance
    The saga continues
    [enclosure.scad]
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2021-07-18 Refine switch_clutch exposure cavity size
    * Employ explicit "clearance" plus tolerance instead of bleed
    * Reduce height, which seemed plenty loose
    * Account for tolerance bleed of switch_clutch grip in math
    In short, tighter vertical grip and looser length (even though value
    sure looks the same)
    [enclosure.scad]
2021-07-19 Refine disassembly_wedge_cavity
    * Widen for wider screwdrivers, picks, or other wedge tools
    * Shorten to newly extracted and measured FLATHEAD_SCREWDRIVER_POINT
    * Move to back where it's less seen, in anticipation of regular usage
    kinda messing up the plastic there
    [enclosure.scad, nuts_and_bolts.scad]
2021-07-20 Refine battery_holder's wire and enclosure fit
    * On battery_holder:
    * Extract recurring wall value
    * Ditch back hitch
    * Add wire channel cavity on front, using measurements from ribbon
    cable. Hoping it provides a little cush against snap fit
    * Reimagine hitches onto the sides
    * Reverse end terminals for new wire layout
    * On enclosure
    * Web back endstop, using newly extracted
    PCB_FIXTURE_BUTTON_RAIL_LENGTH
    * Reduce length now that it's reinforced with webs
    [battery_holder.scad, enclosure.scad, pcb_fixtures.scad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]
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2021-07-20 Move battery_holder wire_channel to bottom
    Previous front channel was too big to print well on wall w/o support or
    changing the wall depth. It was also too tall, but that's less of an
    issue.
    Some commercial battery holders put this channel on/near the bottom,
    running the cable in the gap between the batteries.
    Worth a try!
    [battery_holder.scad]
2021-07-21 Narrow PCB screw hole usage, bring back posts
    Partial revert of 40fe517a66 but skips the center screw as a post.
    Shouldn't be needed w/ the outermost posts for registration.
    [scout.scad]
2021-07-21 Revert "Move batteries back over to the left"
    This reverts commit 8af33eb969e10900a9e6b254ec7ca0a8fde91f63.
    [scout.scad]
2021-07-22 Again, really, center batteries
    The previous, left position wasn't doing much. Its effect on center
    balance wasn't noticeable and it made the front lip tightness
    inconsistent.
    [scout.scad]
2021-07-22 Remove obstructing back PCB fixtures on enclosure bottom
    These were colliding with the new back_corner_reinforcements, which are
    more important.
    Truthfully, the front corners could probably get removed too now, since
    there posts in the mounting holes for registration. :shrug:
    [enclosure.scad, pcb_fixtures.scad]
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2021-07-22 Let battery_holder snap in upside down or reversed
    [battery_holder.scad]
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2021-07-22 Finalize cantilever_length
    * Both the derived unexposed_cantilever_length and the static
    20_KEY_MATRIX_CANTILEVER_LENGTH are too long, which adds more "clicky"
    mechanical noise and is prone to deformation as the mounting screws
    are tightened. Just feels kinda cheap.
    * 3mm is used by the POLY555, in addition to the 1mm height. Nice.
    * Taller heights have a stronger feel but are harder to press. There's
    probably another sweet spot with a longer length and taller height,
    but what we got here is certainly fine for now!
    [scout.scad]
2021-07-23 Reduce Arduino code
    * Fix GLIDE and OCTAVE and ditch control code
    * Remove unused notes and their keys
    * Fix octave math, I think...
    [KeyBuffer.cpp, scout.ino]
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2021-07-23 Finalize Arduino code
    * Remove WiP comments
    * Extract and use BUFFER_MAX
    * Remove TODOs I'm not gonna act on
    * Fix buffer duplicate issue
    * Simplify buffer iterations -- it's never gonna not be an int
    * Fix remaking buffer when there's a removal
    * Tidy KeyBuffer.print
    * Move glide* settings together
    * (Probably) speed up getNoteFrequency
    Don't need redefine that magic number each time
    * Fix inconsistent space formatting
    [KeyBuffer.cpp, scout.ino]
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2021-07-23 Really, revert "HACK Increase enclosure_wall"
    Really unsure how it didn't happen in
    a557dd1f7e9e815718370ad24b7a911133c4af9a.
    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
    [scout.scad]
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2021-07-24 Fix floating battery_holder_fixtures nub
    By a stroke of luck, this wasn't causing issues in PrusaSlicer, but I
    bet other slicers won't be as forgiving.
    [enclosure.scad]
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2021-08-02 Make led_exposure less obvious
    On light plastics, a shade_depth of 3x DEFAULT_DFM_LAYER_HEIGHT has a
    clearly visible inner shadow.
    In testing with yellow PLA, it's around 5x that the outline is no longer
    defined enough to see. At 7x it's completely invisible.
    I'm worried that 5x is too much for darker plastics, which will be more
    common in my prints, so compromising at 4x.
    [enclosure.scad]
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2021-08-04 Remove troublesome red RX LED indicator
    I want to have some indication on the Scout to show when it's being
    re-programmed. Connecting an LED to the ATMega's RX (Receiving) pin
    seemed like a good way to do that.
    PCB REV _B had it connected to the RGB LED's green pin, and this seemed
    to work just fine for both the [Adafruit FTDI cable][0] and the [USB
    Serial Cable from Cornfield Electronics][1].
    But when PCB REV _C swapped the green pin for the red, suddenly the
    Adafruit cable no longer worked, even though the Cornfield one continued
    merrily. Why?!
    Other debugging notes:
    * Both cable brands supply 4.9v on VCC.
    * Regardless of which PCB REV or brand, the RX LED was always semi-lit
    when co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
    [scout.kicad_pcb, scout.sch]
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2021-08-07 Fix back-left PCB fixture stool placement
    Rev A has a UART cutout where it was previously. This change moves it
    and its sinbling into the corners, accounting for chamfer so it
    shouldn't collide with switch_clutch.
    [pcb_fixtures.scad]
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2021-08-09 Center UART cavity against its pins
    The cavity's height and Z were previously tied to the shared label Z,
    which is centered against the whole enclosure height. That's fine but
    makes the cavity look like a mistake because the pin Z isn't also
    centered.
    This change makes the UART cavity centered with its pins, damn alignment
    with the enclosure, and at least as tall as the labels.
    tl;dr: it's a lil taller and the bottom is maybe a mm lower
    [enclosure.scad, scout.scad]
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2021-09-21 Loosen knob fit on pot shaft
    * Increase chamfer for reduced height impact
    * Double tolerance
    [scout.scad]
2021-09-21 Undo now-doubled knob tolerance loosening
    Commit 7e2dab7311 in apc repo makes the same effecitve change on the
    measurement of the pot shaft itself, so hacking it here on tolerance
    actually doubles the loosening.
    Anyway, partially reverts 145f03adf5 in this repo
    [scout.scad]
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
